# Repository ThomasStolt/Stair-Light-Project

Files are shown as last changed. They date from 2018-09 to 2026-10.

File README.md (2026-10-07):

# Stair Light Project

Automatic animated stair lighting with **SK6812 RGBW** LEDs. Two PIR sensors (SR-HC501) at the first and last step detect direction and trigger a random animation. Control via a phone-friendly **web UI** (motion automation on/off, playing animations, fixed colour, device status, settings and birthdays) and optional **night mode** (configurable hours: soft red light only).

- **MCU:** ESP8266 (e.g. NodeMCU)
- **LEDs:** SK6812 RGBW (WS2812-compatible), 27 LEDs per step, 16 steps (configurable)
- **Sensors:** PIR1 = “up”, PIR2 = “down”
- **Boot:** Three soft green-white pulses (2 s) signal “ready”. Motion automation comes back as it was last set (on for a new device).

<div align="center">
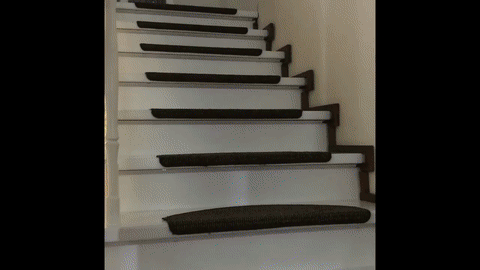
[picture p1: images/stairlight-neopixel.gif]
Stair Light test bed
  
</div>

---

## Requirements

- **Arduino CLI** (e.g. `brew install arduino-cli`)
- **ESP8266 core:**  
  `arduino-cli core update-index && arduino-cli core install esp8266:esp8266`
- **Libraries:**  
  `arduino-cli lib install "Adafruit NeoPixel"`  
  `arduino-cli lib install "EasyNTPClient"`

---

## Project structure

| Folder/File | Description |
|---|---|
| `rgbw_stair_light/` | Main sketch (stair light + OTA) |
| `rgbw_stair_light/parking.h` | Animations and helpers |
| `rgbw_stair_light/web_ui.h` | Web UI page (HTML/CSS/JS, served from flash) |
| `rgbw_stair_light/birthdays.h.example` | Template for birthdays (copy to `birthdays.h`) |
| `schematics/` | KiCad schematic, PCB |
| `images/` | Photos (incl. test bed) |

**Scripts (project root):**

| Script | Purpose |
|---|---|
| `upload-to-esp8266.sh` | Compile + upload **via USB** |
| `upload-to-esp8266-ota.sh` | Upload **via OTA** (WiFi) to one or more devices; compiles only when the sketch changed |
| `upload-ota-firewall-ok.sh` | OTA with **firewall temporarily disabled** (macOS) |
| `setup-firewall-ota.sh` | Add firewall rule for OTA (macOS, sudo) |

---

## Setup

### 1. WiFi and hostname

Credentials go in **`rgbw_stair_light/credentials.h`** (gitignored).

- Copy `credentials.h.example` to `credentials.h` and set:
  - `WIFI_SSID` – your Wi‑Fi name  
  - `WIFI_PASS` – Wi‑Fi password  
  - `OTA_HOSTNAME` – e.g. `stairlight-testbed` or `stairlight`

Without `credentials.h` the build fails.

> The hostname can also be changed at runtime in the web UI (**Settings** section); it is stored in flash and applied on the next reboot. `OTA_HOSTNAME` in `credentials.h` is only the default used on first boot.

### 2. Birthdays (optional)

On dates listed in **`rgbw_stair_light/birthdays.h`**, only the birthday animation runs.

- **`birthdays.h`** is in `.gitignore` and is not committed.
- Copy `birthdays.h.example` to `birthdays.h`, set `BIRTHDAY_COUNT` and the `BIRTHDAY(month, day)` list (e.g. `BIRTHDAY(3, 15)` = 15 March).
- Without `birthdays.h` the build fails – after cloning, copy the example (use 0 entries if you don’t need birthdays).

### 3. Firewall (macOS, only if OTA fails)

If OTA fails with the firewall on:

- **Option A – rule via CLI:**  
  `sudo ./setup-firewall-ota.sh`  
  (allows Arduino Python and Terminal/Cursor to accept incoming connections)

- **Option B – OTA with firewall briefly off:**  
  `./upload-ota-firewall-ok.sh stairlight-testbed.local`  
  (firewall is disabled only during the upload, then re-enabled)

---

## First upload: via USB

1. Connect the ESP8266 via USB.
2. Check port (optional):  
   `arduino-cli board list`
3. From the project folder run:

   ```bash
   ./upload-to-esp8266.sh
   ```

   Default port is `/dev/cu.usbserial-0001`. To use another port:

   ```bash
   ./upload-to-esp8266.sh /dev/cu.wchusbserial-12345
   ```

4. After a successful upload the ESP connects to Wi‑Fi and is ready for OTA.

---

## Upload via OTA (WiFi)

Prerequisite: the ESP is already running firmware with **ArduinoOTA** (e.g. after the first USB upload) and is on the same Wi‑Fi network. The OTA script uses **espota.py** (no board discovery required); pass the ESP’s IP or mDNS hostname.

- **By hostname (mDNS):**  
  ```bash
  ./upload-to-esp8266-ota.sh stairlight-testbed.local
  ```

- **By IP:**  
  ```bash
  ./upload-to-esp8266-ota.sh 192.168.2.185
  ```

- **Several devices in one go** (same build for all, password asked once):  
  ```bash
  ./upload-ota-firewall-ok.sh 192.168.1.50 192.168.1.51
  ```

The IP is shown in the serial monitor after “Connected, IP address:” or “Web server: http://…”.

**Web UI:** Open `http://<IP>` or `http://<hostname>.local` in a browser. The page is made for phones. Its fonts load from Google Fonts when the phone has internet; without internet it uses the system font.

- **Header** – Device name, WiFi network and the device's local time (NTP).
- **Notices** – Night mode with its hours (“Night mode active” during night hours), and “Not connected, retrying” when the device can't be reached.
- **Motion automation** – On/off switch. The setting is saved on the device and survives restarts and power cuts.
- **Play an animation** – Tiles with live previews: Rainbow, Star sparkle, Birthday, Night red, White ramp and Matrix. A tap plays the animation for 10 s (Matrix: 60 s, `MATRIX_WEB_MS`). The tile of the animation that is running, whether started from the page or by motion, shows a progress ring.
- **Fixed colour** – Sliders for the red, green, blue and white LEDs (0–100 %) with a colour preview, and **All** presets (Off, 25 %, 50 %, 75 %, 100 %). Shown on the stairs while motion automation is off.
- **Recent motion** – The last 5 motion triggers with direction, animation and time.
- **Device** – Memory, flash and WiFi signal at a glance (percent and absolute values), last restart and uptime, plus a table with IP, gateway, DNS, network and channel, access point, reconnects, CPU, restart reason, free memory, largest free block, fragmentation and space left for updates.
- **Settings** – Device name (applied after a restart), night mode on/off and its hours.
- **Birthdays** – Add, edit and remove up to 20 birthdays.
- **Restart device** – With a confirmation on the page.
- **Firmware version** – At the bottom of the page.

The browser caches the page for an hour, so reload it after a firmware update. The page talks to the device through a small JSON API: `GET /api/state` (automation, colour, night mode, running animation), `/api/time`, `/api/log`, `/api/memory`, `/api/sysinfo`, `/api/settings`, `/api/birthdays`, and `POST /api/auto`, `/api/color`, `/api/play` (`anim=2..7`), `/api/settings`, `/api/birthdays`, `/api/reboot`. The web server keeps answering while an animation runs; OTA uploads only work between animations.

**If the firewall (macOS) blocks OTA:**  
Use the wrapper script instead of `upload-to-esp8266-ota.sh`:

```bash
./upload-ota-firewall-ok.sh stairlight-testbed.local
```

The firewall is then disabled only during the upload and re-enabled afterwards.

**espota debug output:**  
```bash
./upload-to-esp8266-ota.sh stairlight-testbed.local --debug
```

---

## Serial monitor

Baud rate: **115200**.

- **Via task (Cursor/VS Code):**  
  `Cmd+Shift+P` → “Tasks: Run Task” → “Serial Monitor (115200 Baud)” → enter port.

- **Via terminal:**  
  ```bash
  arduino-cli monitor -p /dev/cu.usbserial-0001 -c baudrate=115200
  ```

Adjust the port if needed (`arduino-cli board list`). Exit with `Ctrl+C`. While the monitor is running the USB port is in use (no upload).

**Note:** With `USE_SERIAL.setDebugOutput(true)` in the sketch, the ESP8266 WiFi library also prints connection messages (`state:`, `reconnect`, `scandone`, etc.). For a quieter monitor you can set `setDebugOutput(false)` to see only PIR/NTP and your own messages.

---

## Night mode (1–6 h)

Between **1:00 and 6:00 local time** (NTP + auto CET/CEST):

- Only the **night animation** runs: soft breathing red, max 20% brightness, **never fully off** (minimum brightness is configurable).
- PIR triggers the night animation; manual web colours have no effect.
- After 6:00 the strip turns off and normal behaviour (automation/manual) applies again.
- The web UI shows a **“Night mode active”** notice during night hours.

The night animation can be tested anytime in the web UI: tap **Night red** under **Play an animation** (10 s).

---

## Birthdays

Birthdays (month, day, and an optional name) trigger the birthday animation on the day.
They are editable in the web UI under **Birthdays** — add or remove rows and click Save —
and are stored in flash (up to 20 entries), surviving reboots. `birthdays.h` is only the
first-boot default; after that the saved list is authoritative.

API:

```bash
curl http://<host>/api/birthdays
# [{"m":11,"d":19,"name":"Anna"}, ...]
```

`POST /api/birthdays` replaces the whole list (form-encoded: `count=N` then `m<i>`,
`d<i>`, `n<i>` for each entry). Months 1–12, days 1–31, names up to 19 characters
(letters, digits, space, `-` `_` `.`).

## External control API

Another process on the same network can drive the strip directly, bypassing motion
detection — e.g. a parking/garage helper signalling stop/go.

`POST /api/ext` with form field `state`:

| `state` | Effect |
|---|---|
| `red` | Solid red, held until the next command |
| `red_blink` | Red blinking every 500 ms |
| `green_fade` | Green dimming from full to off over ~30 s, then auto-clears |
| `yellow_blink` | Yellow (red + green) blinking every 500 ms |
| `clean` | All LEDs fade up to near-max (R+G+B+W = 250) for cleaning; fades out on stop; auto-off after 10 min |
| `clear` | LEDs off immediately, override released |

While a command is active, motion detection is suppressed. After `green_fade` finishes
(or `clear`), normal behaviour resumes — daytime automation, or night mode if within
the configured night hours. No authentication (trusted LAN only). An `/api/ext` command
also **interrupts a running motion animation** (it aborts within ~1–2 s rather than
waiting for the animation and its post-delay to finish).

The held states (`red`, `red_blink`, `yellow_blink`) stay active until the next command,
but have a **5-minute safety timeout**: if no new `/api/ext` command arrives within 5
minutes, the override releases automatically and normal operation resumes (so the stairs
can't get stuck if the controller crashes or loses WiFi). Each command resets the timer.
`green_fade` self-terminates after ~30 s.

```bash
curl -X POST -d state=red        http://<host>/api/ext
curl -X POST -d state=red_blink    http://<host>/api/ext
curl -X POST -d state=green_fade   http://<host>/api/ext
curl -X POST -d state=yellow_blink http://<host>/api/ext
curl -X POST -d state=clean        http://<host>/api/ext
curl -X POST -d state=clear        http://<host>/api/ext
```

### Siri / Apple Shortcuts ("Staubsaugen")

Siri can't call the ESP directly, but an Apple **Shortcut** can, and Siri runs Shortcuts by
name. Create two shortcuts in the Shortcuts app (iPhone/iPad/Mac):

1. **"Staubsaugen"** (cleaning light on):
   - Add action **Get Contents of URL**
   - URL: `http://stairlight.local/api/ext` (or the device IP, e.g. `http://<device-ip>/api/ext`)
   - Method: **POST**, Request Body: **Form**, add field `state` = `clean`
2. **"Staubsaugen aus"** (off):
   - Same action/URL, field `state` = `clear`

Then say **"Hey Siri, Staubsaugen!"** to turn all LEDs to full brightness (auto-off after
10 minutes) and **"Hey Siri, Staubsaugen aus!"** to turn it off. The device must be reachable
on the same network (mDNS name `stairlight.local`, or use a DHCP-reserved IP).

#### Siri / Kurzbefehle einrichten (Deutsch)

Siri kann den ESP nicht direkt ansprechen, aber Siri führt **Kurzbefehle** (Shortcuts)
per Namen aus. Lege dafür zwei Kurzbefehle in der **Kurzbefehle**-App (iPhone/iPad/Mac) an:

1. **Kurzbefehl „Staubsaugen"** (Licht an):
   - Aktion **„Inhalte von URL abrufen"** hinzufügen
   - URL: `http://stairlight.local/api/ext` (oder die Geräte-IP, z. B. `http://<device-ip>/api/ext`)
   - Auf **▸ Mehr anzeigen** tippen: **Methode** = `POST`, **Anfragetext** = `Formular`,
     Feld **`state`** = `clean`
2. **Kurzbefehl „Staubsaugen aus"** (Licht aus): gleich wie oben, aber Feld **`state`** = `clear`

Dann **„Hey Siri, Staubsaugen!"** schaltet alle LEDs auf volle Helligkeit (sanft hochdimmen,
automatische Abschaltung nach 10 Minuten) und **„Hey Siri, Staubsaugen aus!"** dimmt wieder
herunter. Hinweise: Das iPhone muss im selben WLAN sein; beim ersten Mal fragt iOS nach der
Erlaubnis für das lokale Netzwerk → **Erlauben**. Falls `stairlight.local` nicht auflöst, die
IP verwenden (am besten im Router eine feste IP / DHCP-Reservierung vergeben).

Night mode (enable + start/end hours) and the hostname are configurable in the web UI
**Settings** section and persist across reboots.

---

## Sketch configuration

In **`rgbw_stair_light/rgbw_stair_light.ino`** (and `parking.h`):

| Constant | Meaning | Default |
|---|---|---|
| `STEPS` | Number of steps | 16 |
| `WIDTH` | LEDs per step | 27 |
| `ANIM_DURATION` | Duration of a PIR-triggered animation (ms) | 20000 |
| `POST_ANIM_DELAY_MS` | Delay after animation before next trigger (ms) | 10000 |
| `BRIGHTNESS` | LED brightness 0–255 | 255 |
| `DEBUG` | 1 = PIR/trigger on serial monitor | 1 |
| `TIMEZONE_OFFSET_SEC` | Seconds UTC→local (e.g. 3600 for CET) | 3600 |
| `FW_VERSION` | Firmware version string shown in web UI | "2.1.0" |
| `NIGHT_HOUR_START` / `NIGHT_HOUR_END` | Night mode from hour … to (excl.) | 1, 6 |
| `NIGHT_BRIGHTNESS_MAX` / `NIGHT_BRIGHTNESS_MIN` | Red in night mode max/min (0–255) | 50, 10 |

Pins (see comments in sketch): NeoPixel = GPIO 14 (D5), PIR1 = GPIO 16 (D0), PIR2 = GPIO 4 (D2). Do not use GPIO 15 and 2 (boot behaviour).

---

## Animations

Direction (up/down) is detected via PIR1/PIR2. With stair automation on, a random one of these animations runs (no back-to-back repeat):

- **Rainbow** (`rainbowSteps`) – steps fade in as a wave, colours flow in walking direction  
- **White ramp** (`FadeToFullBrightness`) – all steps to white  
- **Star sparkle** (`starSparkle`) – dark blue backdrop with white stars that light up and fade out  
- **Matrix** (`matrixRain`) – green digital rain falling down the stairs

On **birthdays** (from the web UI / `birthdays.h`) the **birthday animation** runs instead: random colours on about three quarters of the LEDs, each glowing and fading. At night (night mode hours) motion turns on a soft red light (**Night red**, `nightAnimation`).

In the web UI you can play each of these, plus Birthday and Night red, for 10 seconds (Matrix: 60 seconds).

More functions and possible new animations are in **`parking.h`**.

---

## License / contact

Originally from October 2016; sketch and structure have been extended (OTA, credentials, web API, night mode, birthdays, firewall workaround, date/time, reboot, motion log, memory status table, All presets, automation on by default, OTA via espota.py, night mode indicator, firmware version display).

For questions or ideas for new animations, contact the repository owner.

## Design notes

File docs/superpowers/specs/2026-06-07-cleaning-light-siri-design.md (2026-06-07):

# Cleaning Light ("Staubsaugen") + Siri — Design

**Date:** 2026-06-07
**Component:** `rgbw_stair_light/rgbw_stair_light.ino` (+ README, CHANGELOG); Apple Shortcuts (user side)
**Status:** Approved

## Goal

A voice-triggered "cleaning light": "Hey Siri, Staubsaugen!" turns every LED to full
brightness for vacuuming, and it stays on for **10 minutes** or until "Hey Siri,
Staubsaugen aus!" turns it off. Brightness = **all channels at 255** (R+G+B+W max),
per user choice (brightest; note the high sustained current draw across 432 LEDs).

## Approach

Reuse the existing external-control state machine (`/api/ext`) — it already provides a
held override that suppresses motion automation and night mode while active and restores
normal operation when released. Add a new held state `clean`:

- `POST /api/ext state=clean` → all LEDs `setAll(255,255,255,255)`, held.
- Auto-off after **10 minutes** (its own timeout, distinct from the 5-min timeout used by
  the red/yellow held states). Each `clean` command resets the timer.
- `POST /api/ext state=clear` → off, override released (this is "Staubsaugen aus").

Siri integration is done with two Apple Shortcuts (no firmware involvement): a Shortcut
named **"Staubsaugen"** that POSTs `state=clean`, and **"Staubsaugen aus"** that POSTs
`state=clear`. Saying "Hey Siri, <shortcut name>" runs the matching Shortcut.

## Firmware changes

1. `enum ExtMode` gains `EXT_CLEAN`; command code `6`.
2. `#define EXT_CLEAN_TIMEOUT_MS 600000uL` (10 min).
3. `handleApiExt()` accepts `state=clean` → cmd 6 (and the help/error strings list it).
4. `applyExtCommand()` case 6: `EXT_CLEAN`, `g_extActive=true`, `setAll(255,255,255,255)`,
   `strip.show()`. (`g_extLastCmdMs` is already set for every command at the top.)
5. `serviceExtControl()` timeout guard includes `EXT_CLEAN`, using `EXT_CLEAN_TIMEOUT_MS`
   instead of the 5-min `EXT_HOLD_TIMEOUT_MS` for that mode; on timeout it clears
   (LEDs off, `EXT_NONE`, `g_extActive=false`) exactly like the other held states. `clean`
   is a solid state, so the blink/fade branches don't touch it.

No new routes; reuses `POST /api/ext`.

## Siri / Apple Shortcuts (documented for the user)

Two Shortcuts (Shortcuts app → +):
- **"Staubsaugen"**: action *Get Contents of URL* → `http://stairlight.local/api/ext`,
  Method `POST`, Request Body `Form`, field `state` = `clean`.
- **"Staubsaugen aus"**: same URL, `state` = `clear`.

"Hey Siri, Staubsaugen" / "Hey Siri, Staubsaugen aus" then trigger them. (Phone must be on
the same WiFi / reachable; `stairlight.local` resolves via mDNS, or use the IP.)

## Error handling / edge cases

- Re-sending `clean` resets the 10-min timer (keepalive).
- Works during night hours (override suppresses night mode); normal behaviour resumes on
  timeout/clear.
- `millis()` subtraction is rollover-safe.
- Power: all-channels-255 for 432 LEDs is a heavy sustained load — documented as a caution.

## Testing

Compile clean; on-device: `state=clean` → strip full white, `state=clear` → off + normal
resumes. (Full 10-min wait impractical by hand; timeout uses the same proven path as the
existing held-state timeout.)

## Out of scope

- A dedicated `/api/clean` route (reusing `/api/ext` is simpler).
- Configurable brightness/duration via the API or UI.

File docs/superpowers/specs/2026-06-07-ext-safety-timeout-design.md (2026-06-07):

# External-Control Safety Timeout — Design

**Date:** 2026-06-07
**Component:** `rgbw_stair_light/rgbw_stair_light.ino` (+ README, CHANGELOG)
**Status:** Approved

## Goal

Prevent the stairs from getting stuck in an external-control state. The held states
(`red`, `red_blink`, `yellow_blink`) currently stay active indefinitely until the
controller sends another command. If the controller crashes or loses WiFi, the strip
would remain overridden forever. Add a **5-minute safety timeout**: if no new `/api/ext`
command arrives within 5 minutes, the override releases automatically and normal operation
(motion automation / night mode, exactly as before) resumes.

## Decisions

- **Timeout:** 5 minutes (300 s).
- **Applies to:** the held states only — `red`, `red_blink`, `yellow_blink`. `green_fade`
  already self-terminates after ~30 s, so the timeout is irrelevant to it (and not applied).
- **Reset on activity:** every received `/api/ext` command resets the 5-minute timer
  (timer is measured from the last command, not from the first).
- **On timeout:** identical to `clear` — LEDs off, `g_extActive=false`, `g_extMode=EXT_NONE`;
  `loop()` then resumes whatever normal behaviour was in effect before (automation on/off is
  never modified by external control, so "normal operations from before" is preserved).

## Implementation

In the existing external-control state machine:

1. `#define EXT_HOLD_TIMEOUT_MS 300000uL` (5 min).
2. New global `unsigned long g_extLastCmdMs = 0;` — timestamp of the most recent command.
3. `applyExtCommand()` sets `g_extLastCmdMs = millis()` for every command (resets the timer).
4. `serviceExtControl()` (already called every loop iteration while `g_extActive`) gets a
   guard at the top: if the current mode is `EXT_RED` / `EXT_RED_BLINK` / `EXT_YELLOW_BLINK`
   and `millis() - g_extLastCmdMs >= EXT_HOLD_TIMEOUT_MS`, turn LEDs off, set
   `g_extMode=EXT_NONE`, `g_extActive=false`, and return. `green_fade` is excluded.

`millis()` subtraction is rollover-safe (unsigned). No change to the API surface, routes,
or any other behaviour.

## Error handling / edge cases

- A new command mid-hold resets the timer (controller "keepalive" keeps a state active).
- `clear` and `green_fade` are unaffected (clear releases immediately; green_fade ends in 30 s).
- Rollover at ~49 days is handled by the unsigned `now - g_extLastCmdMs` idiom.

## Testing

No unit harness (firmware). Verify: compile clean; on-device, send `red`/`yellow_blink`,
confirm it holds, then send `clear` to stop (full 5-min wait is impractical to verify by
hand but the logic mirrors the proven `green_fade` auto-clear). Confirm normal operation
resumes after `clear`/timeout.

## Out of scope

- Per-command custom durations (`secs=`).
- Applying the timeout to `green_fade` (already self-terminating).

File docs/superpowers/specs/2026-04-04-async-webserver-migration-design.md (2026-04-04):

# AsyncWebServer Migration & Web UI Redesign

**Date:** 2026-04-04
**Status:** Approved

## Goal

Migrate from `ESP8266WebServer` (synchronous) to `ESPAsyncWebServer` (async) for improved web UI responsiveness, and redesign the web UI with sliders, individual animation buttons, collapsible diagnostics, and tiered polling.

## Approach: Incremental (Two Phases)

Phase 1 swaps the server library while keeping the existing UI identical. Phase 2 redesigns the UI. This separation ensures that if something breaks, the cause is obvious — library vs. UI change.

## Constraints

- ESP8266 (NodeMCU), ~37 kB free heap available
- HTML stays embedded in PROGMEM (no LittleFS) — single OTA binary deploy
- OTA must remain functional throughout
- All existing API response formats preserved

---

## Phase 1: AsyncWebServer Library Swap

### Dependencies

Replace:
- `#include <ESP8266WebServer.h>`

With:
- `#include <ESPAsyncTCP.h>`
- `#include <ESPAsyncWebServer.h>`

### Server Declaration

```cpp
// Before
ESP8266WebServer server(80);

// After
AsyncWebServer server(80);
```

### Handler Conversion

All handlers change signature from using the global `server` object to receiving an `AsyncWebServerRequest*` parameter.

**Pattern:**
```cpp
// Before
void handleApiState() {
  server.sendHeader(F("Cache-Control"), F("no-store"));
  server.send(200, F("application/json"), json);
}

// After
void handleApiState(AsyncWebServerRequest *request) {
  AsyncWebServerResponse *response = request->beginResponse(200, F("application/json"), json);
  response->addHeader(F("Cache-Control"), F("no-store"));
  request->send(response);
}
```

**Parameter access changes:**
- `server.hasArg(F("on"))` → `request->hasParam(F("on"), true)` (second arg `true` = POST body param)
- `server.arg(F("on"))` → `request->getParam(F("on"), true)->value()`
- `server.method() != HTTP_POST` checks are no longer needed — routes are registered with `HTTP_POST` method directly, so only matching methods reach the handler

### Route Registration

```cpp
// Before
server.on(F("/"), handleIndex);
server.on(F("/api/state"), HTTP_GET, handleApiState);
server.on(F("/api/auto"), HTTP_POST, handleApiAuto);

// After
server.on("/", HTTP_GET, handleIndex);
server.on("/api/state", HTTP_GET, handleApiState);
server.on("/api/auto", HTTP_POST, handleApiAuto);
```

Note: `AsyncWebServer::on()` does not accept `F()` macro for the path string. Use plain string literals.

### Remove handleNetwork()

Delete the `handleNetwork()` function (lines 164, 168–171 in .ino) and remove all calls to it:
- ~5 calls in `rgbw_stair_light.ino` (main loop, wait loops)
- ~17 calls in `parking.h` (inside animation loops)

With AsyncWebServer, requests are handled via interrupts — no manual pumping is needed.

`ArduinoOTA.handle()` still needs to be called in `loop()` — move it from `handleNetwork()` to the main loop directly.

### Remove server.handleClient()

No longer needed — delete from loop and from `handleApiReboot`.

### Refactor handleApiPlay (Flag-Based)

The current handler runs animations synchronously inside the request handler. AsyncWebServer handlers must return quickly (they execute in the TCP context).

**Solution:** Handler sets a flag, `loop()` picks it up:

```cpp
volatile int g_pendingPlayAnim = 0;  // 0 = none, 1–6 = animation to play

void handleApiPlay(AsyncWebServerRequest *request) {
  if (!request->hasParam("anim", true)) {
    request->send(400, F("text/plain"), F("anim=1..6"));
    return;
  }
  int anim = request->getParam("anim", true)->value().toInt();
  if (anim < 1 || anim > 6) {
    request->send(400, F("text/plain"), F("anim 1..6"));
    return;
  }
  g_pendingPlayAnim = anim;
  request->send(204);
}

// In loop(), after handleNetwork removal:
if (g_pendingPlayAnim > 0) {
  int anim = g_pendingPlayAnim;
  g_pendingPlayAnim = 0;
  // run animation (same logic as current handleApiPlay body)
}
```

### Refactor handleApiReboot (Flag-Based)

Like `handleApiPlay`, the reboot handler must not block. Use a flag that `loop()` checks:

```cpp
volatile bool g_pendingReboot = false;

void handleApiReboot(AsyncWebServerRequest *request) {
  g_pendingReboot = true;
  request->send(204);
}

// In loop():
if (g_pendingReboot) {
  delay(300);  // give async stack time to flush the 204 response
  ESP.restart();
}
```

### Thread Safety Note

AsyncWebServer on ESP8266 uses async TCP callbacks (from the lwIP stack), not a separate thread. The ESP8266 is single-core with cooperative multitasking. Shared variables (`g_pendingPlayAnim`, `g_pendingReboot`, `manual_r/g/b/w`, `automationOn`) are accessed from both async callbacks and `loop()`. On ESP8266 this is safe for simple flag/value reads and writes (single-core, no preemption between instructions), but avoid multi-step read-modify-write sequences in handlers.

### Phase 1 Verification

After Phase 1, all existing endpoints must work identically:
- `GET /` serves the same HTML
- `GET /api/state`, `/api/time`, `/api/log`, `/api/memory`, `/api/sysinfo` return same JSON formats
- `POST /api/auto`, `/api/color`, `/api/alloff`, `/api/play`, `/api/reboot` behave the same
- OTA upload works
- PIR-triggered animations work
- Night mode works
- Web UI functions identically (it's the same HTML)

---

## Phase 2: Web UI Redesign

### Layout: Collapsible Diagnostics

Top-to-bottom, single scrollable page:

1. **Header**: "Stair Light" title, date, time, uptime, last reboot
2. **Automation**: On/Off toggle buttons + night mode badge (conditional)
3. **RGBW Sliders**: One `<input type="range">` per channel (0–100%), colored LED indicator dot, percentage label
4. **All-Channel Presets**: Row of buttons: 0% / 25% / 50% / 75% / 100%
5. **Animation Buttons**: 6 individual color-coded buttons (one per animation)
6. **Reboot**: Single button
7. **Collapsible Diagnostics** (using `<details>/<summary>`):
   - Last 5 motions (table)
   - Memory status (table: heap/flash/RTC)
   - CPU / Runtime (table: freq, reset reason)
   - WiFi (table: SSID, RSSI, IP, gateway, DNS, channel, reconnects)
8. **Footer**: Firmware version

### RGBW Sliders

Each channel row:
```
[colored dot] =====[slider]===== [percentage%]
```

- HTML: `<input type="range" min="0" max="100" value="0">`
- Slider track styled to match channel color (red/green/blue/white)
- On `input` event, debounced to ~100ms, sends POST to `/api/color`

### API Addition: Direct Value Set

Add `v=<0-100>` parameter to `/api/color` for direct value setting (used by sliders):

```
POST /api/color
Body: c=r&v=70
```

Sets channel `r` to exactly 70%. Existing `a=minus`/`a=plus`/`a=toggle` parameters continue to work (backward compatible). The preset buttons use: `POST /api/color` with `all=<value>` (unchanged).

### Animation Buttons

Six buttons, each sending `POST /api/play` with `anim=1..6`:

| Button | Animation | Color Theme |
|---|---|---|
| Random fade | `anim=1` | Green |
| Rainbow | `anim=2` | Blue/cyan |
| White ramp | `anim=3` | White/gray |
| Star sparkle | `anim=4` | Dark blue/purple |
| Birthday | `anim=5` | Pink/magenta |
| Night red | `anim=6` | Red |

Buttons show a pressed/active state on tap for visual feedback.

### Tiered Polling

**Fast tier — every 2 seconds:**
- `GET /api/state` — automation status, RGBW percentages, night mode flag
- `GET /api/time` — date, time, uptime, last reboot

**Slow tier — every 15 seconds, only when expanded:**
- `GET /api/log` — only polled when "Last 5 motions" `<details>` is open
- `GET /api/memory` — only polled when "Memory status" `<details>` is open
- `GET /api/sysinfo` — only polled when "CPU/Runtime" or "WiFi" `<details>` is open

When all diagnostic sections are collapsed, only 2 requests every 2 seconds (down from 5 every 1 second = 60% reduction in baseline traffic).

### Slider Debouncing

As the user drags a slider, `input` events fire rapidly. To avoid flooding the ESP:
- Track the latest value per channel
- Use a 100ms debounce timer — only send the POST when 100ms have passed since the last `input` event
- This means at most ~10 requests/second during active dragging, and the ESP always gets the final value

### Styling

- Dark theme preserved (`background: #1a1a1a`, light text)
- Same overall aesthetic as current UI (dark card backgrounds, colored accents)
- Mobile-first, max-width ~420px, responsive
- `<details>` elements styled to match the dark theme

---

## Files Modified

- `rgbw_stair_light/rgbw_stair_light.ino` — server library swap, handler conversion, HTML rewrite, new `v=` param in handleApiColor
- `rgbw_stair_light/parking.h` — remove all `handleNetwork()` calls

## Files Not Modified

- `rgbw_stair_light/credentials.h`
- `rgbw_stair_light/birthdays.h`
- Upload scripts (`upload-to-esp8266.sh`, `upload-to-esp8266-ota.sh`)
- Animation logic in `parking.h` (only `handleNetwork()` removal)

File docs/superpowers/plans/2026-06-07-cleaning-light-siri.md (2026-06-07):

# Cleaning Light ("Staubsaugen") + Siri — Implementation Plan

> Direct implementation. Adds a `clean` held state to the existing `/api/ext` machine with a 10-minute auto-off. Compile gate: `arduino-cli compile --fqbn esp8266:esp8266:nodemcu rgbw_stair_light`.

**File:** `rgbw_stair_light/rgbw_stair_light.ino` (+ `CHANGELOG.md`, `README.md`). Siri side = Apple Shortcuts (documented, no code).

## Steps

1. **Enum + command code.** `enum ExtMode { ... , EXT_YELLOW_BLINK };` → append `, EXT_CLEAN`. Update the `g_pendingExtCmd` comment to add `,6=clean`.
2. **Timeout define.** After `#define EXT_HOLD_TIMEOUT_MS 300000uL ...` add `#define EXT_CLEAN_TIMEOUT_MS 600000uL // clean (full brightness) auto-clears after 10 min`.
3. **Handler.** In `handleApiExt()`: add `else if (s == F("clean")) cmd = 6;`; add `clean` to the comment and both 400 help strings (`state=red|red_blink|green_fade|yellow_blink|clean|clear`).
4. **applyExtCommand().** Add before `case 4`:
   ```cpp
   case 6: // clean – all channels full brightness, held (10 min timeout)
     g_extMode = EXT_CLEAN; g_extActive = true;
     setAll(255, 255, 255, 255); strip.show();
     break;
   ```
5. **serviceExtControl() timeout guard.** Replace the held-state timeout block with one that includes `EXT_CLEAN` and uses a per-mode timeout:
   ```cpp
   if (g_extMode == EXT_RED || g_extMode == EXT_RED_BLINK ||
       g_extMode == EXT_YELLOW_BLINK || g_extMode == EXT_CLEAN) {
     unsigned long holdTimeout = (g_extMode == EXT_CLEAN) ? EXT_CLEAN_TIMEOUT_MS : EXT_HOLD_TIMEOUT_MS;
     if (now - g_extLastCmdMs >= holdTimeout) {
       setAll(0, 0, 0, 0); strip.show();
       g_extMode = EXT_NONE;
       g_extActive = false;
       return;
     }
   }
   ```
6. **Version:** `FW_VERSION` `2.4.0` → `2.5.0`.
7. **Docs:** CHANGELOG `2.5.0` entry; README — add `clean` to the `/api/ext` table + a "Siri / Apple Shortcuts" subsection with the two Shortcut definitions.
8. **Compile, commit, OTA-flash to device, push to GitHub.**

## Self-review

- `clean` = all-channels-255, held, 10-min auto-off; `clear` = off ("Staubsaugen aus") ✓.
- Per-mode timeout (10 min for clean, 5 min for others) ✓; timer reset on every command ✓.
- Solid state — not touched by blink/fade branches ✓. Rollover-safe ✓. No new routes ✓.
- Siri documented as two Shortcuts POSTing `state=clean` / `state=clear` ✓.

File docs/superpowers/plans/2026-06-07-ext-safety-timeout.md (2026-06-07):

# External-Control Safety Timeout — Implementation Plan

> Direct implementation (single small, mechanical change to the existing ext state machine). Compile gate: `arduino-cli compile --fqbn esp8266:esp8266:nodemcu rgbw_stair_light`.

**Goal:** Held external-control states (`red`, `red_blink`, `yellow_blink`) auto-release after 5 minutes with no new `/api/ext` command, returning to normal operation.

**File:** `rgbw_stair_light/rgbw_stair_light.ino` (+ `CHANGELOG.md`, `README.md`).

## Steps

1. **Define + global.** After `bool g_extBlinkOn = false;` add:
   - `#define EXT_HOLD_TIMEOUT_MS 300000uL  // 5 min`
   - `unsigned long g_extLastCmdMs = 0;     // last /api/ext command time (for hold timeout)`
2. **Reset timer on every command.** In `applyExtCommand()`, after `unsigned long now = millis();`, add `g_extLastCmdMs = now;`.
3. **Timeout guard.** At the top of `serviceExtControl()` (after `unsigned long now = millis();`), before the blink/fade branches:
   ```cpp
   // Safety timeout: a held state auto-clears after 5 min with no new command,
   // so the stairs can't get stuck if the controller dies. green_fade is excluded
   // (it self-terminates in ~30 s).
   if (g_extMode == EXT_RED || g_extMode == EXT_RED_BLINK || g_extMode == EXT_YELLOW_BLINK) {
     if (now - g_extLastCmdMs >= EXT_HOLD_TIMEOUT_MS) {
       setAll(0, 0, 0, 0); strip.show();
       g_extMode = EXT_NONE;
       g_extActive = false;     // normal behaviour resumes next iteration
       return;
     }
   }
   ```
4. **Version:** bump `FW_VERSION` `2.3.0` → `2.4.0`.
5. **Docs:** CHANGELOG `2.4.0` entry; README external-control section notes the 5-min auto-release for held states.
6. **Compile, merge to master, OTA-flash to the device, push to GitHub.**

## Self-review

- Held states covered (red/red_blink/yellow_blink); green_fade excluded ✓.
- Timer reset on every command (measured from last command) ✓.
- Timeout path = clear semantics (LEDs off, override released, normal resumes) ✓.
- Rollover-safe unsigned subtraction ✓. No API/route changes ✓.

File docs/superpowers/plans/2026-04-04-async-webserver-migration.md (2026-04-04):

# AsyncWebServer Migration & Web UI Redesign — Implementation Plan

> **For agentic workers:** REQUIRED SUB-SKILL: Use superpowers:subagent-driven-development (recommended) or superpowers:executing-plans to implement this plan task-by-task. Steps use checkbox (`- [ ]`) syntax for tracking.

**Goal:** Migrate from ESP8266WebServer to ESPAsyncWebServer for non-blocking request handling, then redesign the web UI with sliders, animation buttons, collapsible diagnostics, and tiered polling.

**Architecture:** Two-phase incremental approach. Phase 1 (Tasks 1–3) swaps the server library while keeping the existing UI identical, so any breakage is clearly a library issue. Phase 2 (Tasks 4–6) redesigns the UI HTML/JS/CSS. All HTML stays embedded in PROGMEM.

**Tech Stack:** ESP8266 Arduino, ESPAsyncTCP, ESPAsyncWebServer, Adafruit NeoPixel, ArduinoOTA, EasyNTPClient

---

## File Structure

| File | Action | Responsibility |
|---|---|---|
| `rgbw_stair_light/rgbw_stair_light.ino` | Modify | Server setup, handlers, HTML, loop logic |
| `rgbw_stair_light/parking.h` | Modify | Remove all `handleNetwork()` calls from animations |

No new files are created.

---

## Phase 1: AsyncWebServer Library Swap

### Task 1: Replace includes, server declaration, and remove handleNetwork()

**Files:**
- Modify: `rgbw_stair_light/rgbw_stair_light.ino:27-41` (includes)
- Modify: `rgbw_stair_light/rgbw_stair_light.ino:92` (server declaration)
- Modify: `rgbw_stair_light/rgbw_stair_light.ino:98-99` (add pending anim/reboot globals)
- Modify: `rgbw_stair_light/rgbw_stair_light.ino:163-171` (handleNetwork declaration and definition)
- Modify: `rgbw_stair_light/parking.h:1` (remove ArduinoOTA include)
- Modify: `rgbw_stair_light/parking.h` (remove all handleNetwork() calls — 17 occurrences)

- [ ] **Step 1: Replace the include and server declaration in the .ino**

In `rgbw_stair_light/rgbw_stair_light.ino`, replace:
```cpp
#include <ESP8266WebServer.h>
```
with:
```cpp
#include <ESPAsyncTCP.h>
#include <ESPAsyncWebServer.h>
```

Replace:
```cpp
ESP8266WebServer server(80);
```
with:
```cpp
AsyncWebServer server(80);
```

- [ ] **Step 2: Add pending animation and reboot flag globals**

In `rgbw_stair_light/rgbw_stair_light.ino`, after line 99 (`uint32_t g_animDurationOverrideMs = 0;`), add:
```cpp
// Flags set by async web handlers, consumed by loop()
volatile int g_pendingPlayAnim = 0;   // 0 = none, 1-6 = animation to play
volatile bool g_pendingReboot = false;
```

- [ ] **Step 3: Remove handleNetwork() declaration and definition**

In `rgbw_stair_light/rgbw_stair_light.ino`, delete lines 163-164:
```cpp
// Called in animations and wait loops so OTA and web server stay responsive during animation
void handleNetwork(void);
```

Delete lines 168-171:
```cpp
void handleNetwork(void) {
  ArduinoOTA.handle();
  server.handleClient();
}
```

- [ ] **Step 4: Remove handleNetwork() calls from parking.h**

In `rgbw_stair_light/parking.h`, delete line 1:
```cpp
#include <ArduinoOTA.h>
```
(ArduinoOTA is already included in the .ino, and parking.h no longer calls handleNetwork which called ArduinoOTA.handle().)

Remove every `handleNetwork();` call in parking.h. These are on lines: 120, 157, 183, 197, 228, 242, 281, 295, 358, 370, 385, 429, 474, 480, 499. Delete each line entirely (they are standalone statements, not part of larger expressions).

- [ ] **Step 5: Remove handleNetwork() calls from the .ino loop**

In `rgbw_stair_light/rgbw_stair_light.ino`, replace every `handleNetwork();` in the loop and wait loops with `ArduinoOTA.handle();`. These are on lines: 732, 778, 790, 818.

The main loop still needs `ArduinoOTA.handle()` since OTA uses a different mechanism than the web server. The web server no longer needs pumping (async handles it).

- [ ] **Step 6: Compile check**

Run:
```bash
arduino-cli compile --fqbn esp8266:esp8266:nodemcuv2 rgbw_stair_light/
```

Expected: compilation errors for handler functions (they still use `server.send()` etc.) — that is fine, we fix those in Task 2. But the handleNetwork removal and includes should be clean.

If ESPAsyncTCP or ESPAsyncWebServer libraries are not installed:
```bash
arduino-cli lib install "ESPAsyncTCP"
arduino-cli lib install "ESP Async WebServer"
```

- [ ] **Step 7: Commit**

```bash
git add rgbw_stair_light/rgbw_stair_light.ino rgbw_stair_light/parking.h
git commit -m "Phase 1a: Replace ESP8266WebServer with ESPAsyncWebServer, remove handleNetwork()"
```

---

### Task 2: Convert all request handlers to async API

**Files:**
- Modify: `rgbw_stair_light/rgbw_stair_light.ino:207-295` (handleIndex)
- Modify: `rgbw_stair_light/rgbw_stair_light.ino:297-308` (handleApiState)
- Modify: `rgbw_stair_light/rgbw_stair_light.ino:310-318` (handleApiAuto)
- Modify: `rgbw_stair_light/rgbw_stair_light.ino:320-356` (handleApiColor)
- Modify: `rgbw_stair_light/rgbw_stair_light.ino:358-364` (handleApiAlloff)
- Modify: `rgbw_stair_light/rgbw_stair_light.ino:367-391` (handleApiPlay)
- Modify: `rgbw_stair_light/rgbw_stair_light.ino:393-432` (handleApiTime)
- Modify: `rgbw_stair_light/rgbw_stair_light.ino:435-442` (handleApiReboot)
- Modify: `rgbw_stair_light/rgbw_stair_light.ino:444-470` (handleApiLog)
- Modify: `rgbw_stair_light/rgbw_stair_light.ino:476-521` (handleApiMemory)
- Modify: `rgbw_stair_light/rgbw_stair_light.ino:539-558` (handleApiSysinfo)

- [ ] **Step 1: Convert handleIndex**

Replace the function with:
```cpp
void handleIndex(AsyncWebServerRequest *request) {
  AsyncWebServerResponse *response = request->beginResponse_P(200, "text/html", PSTR(
    // ... existing HTML string unchanged ...
  ));
  response->addHeader(F("Cache-Control"), F("public, max-age=3600"));
  request->send(response);
}
```

Note: `beginResponse_P` reads from PROGMEM. The HTML content string stays exactly the same as the current version. Keep all the existing HTML between `PSTR(` and `)` identical.

- [ ] **Step 2: Convert handleApiState**

Replace:
```cpp
void handleApiState() {
  String json = "{\"auto\":";
  json += automationOn ? "1" : "0";
  json += ",\"r\":"; json += manual_r;
  json += ",\"g\":"; json += manual_g;
  json += ",\"b\":"; json += manual_b;
  json += ",\"w\":"; json += manual_w;
  json += ",\"night\":"; json += isNightMode(g_lastNtpTime) ? "1" : "0";
  json += "}";
  server.sendHeader(F("Cache-Control"), F("no-store"));
  server.send(200, F("application/json"), json);
}
```
with:
```cpp
void handleApiState(AsyncWebServerRequest *request) {
  String json = "{\"auto\":";
  json += automationOn ? "1" : "0";
  json += ",\"r\":"; json += manual_r;
  json += ",\"g\":"; json += manual_g;
  json += ",\"b\":"; json += manual_b;
  json += ",\"w\":"; json += manual_w;
  json += ",\"night\":"; json += isNightMode(g_lastNtpTime) ? "1" : "0";
  json += "}";
  AsyncWebServerResponse *response = request->beginResponse(200, F("application/json"), json);
  response->addHeader(F("Cache-Control"), F("no-store"));
  request->send(response);
}
```

- [ ] **Step 3: Convert handleApiAuto**

Replace:
```cpp
void handleApiAuto() {
  if (server.method() != HTTP_POST) { server.send(405, F("text/plain"), F("Method Not Allowed")); return; }
  if (server.hasArg(F("on"))) {
    automationOn = (server.arg(F("on")).toInt() != 0);
    if (!automationOn) applyManualColor();
    else { setAll(0, 0, 0, 0); strip.show(); }
  }
  server.send(204);
}
```
with:
```cpp
void handleApiAuto(AsyncWebServerRequest *request) {
  if (request->hasParam(F("on"), true)) {
    automationOn = (request->getParam(F("on"), true)->value().toInt() != 0);
    if (!automationOn) applyManualColor();
    else { setAll(0, 0, 0, 0); strip.show(); }
  }
  request->send(204);
}
```

Note: The `HTTP_POST` method check is removed because the route is registered with `HTTP_POST` — only POST requests reach this handler. The second parameter `true` in `hasParam`/`getParam` means "search POST body parameters".

- [ ] **Step 4: Convert handleApiColor (with new v= parameter)**

Replace the entire `handleApiColor` function with:
```cpp
void handleApiColor(AsyncWebServerRequest *request) {
  if (request->hasParam(F("all"), true)) {
    int pct;
    if (request->hasParam(F("a"), true)) {
      String ax = request->getParam(F("a"), true)->value();
      int cur = (int)manual_r;
      if (ax == F("minus10")) pct = cur - 10;
      else if (ax == F("minus1")) pct = cur - 1;
      else if (ax == F("plus1")) pct = cur + 1;
      else if (ax == F("plus10")) pct = cur + 10;
      else { request->send(400, F("text/plain"), F("a=minus10|minus1|plus1|plus10")); return; }
      if (pct < 0) pct = 0;
      if (pct > 100) pct = 100;
    } else {
      pct = request->getParam(F("all"), true)->value().toInt();
      if (pct < 0) pct = 0;
      if (pct > 100) pct = 100;
    }
    manual_r = manual_g = manual_b = manual_w = (uint8_t)pct;
    if (!automationOn) applyManualColor();
    request->send(204);
    return;
  }
  // Direct value set: c=<channel>&v=<0-100> (used by sliders in Phase 2)
  if (request->hasParam(F("c"), true) && request->hasParam(F("v"), true)) {
    String c = request->getParam(F("c"), true)->value();
    int val = request->getParam(F("v"), true)->value().toInt();
    if (val < 0) val = 0;
    if (val > 100) val = 100;
    uint8_t* target = nullptr;
    if (c == F("r")) target = &manual_r;
    else if (c == F("g")) target = &manual_g;
    else if (c == F("b")) target = &manual_b;
    else if (c == F("w")) target = &manual_w;
    if (!target) { request->send(400, F("text/plain"), F("c=r|g|b|w")); return; }
    *target = (uint8_t)val;
    if (!automationOn) applyManualColor();
    request->send(204);
    return;
  }
  // Step adjust: c=<channel>&a=minus|plus|toggle
  if (!request->hasParam(F("c"), true) || !request->hasParam(F("a"), true)) {
    request->send(400, F("text/plain"), F("c and a (or v) required"));
    return;
  }
  String c = request->getParam(F("c"), true)->value();
  String a = request->getParam(F("a"), true)->value();
  uint8_t* v = nullptr;
  if (c == F("r")) v = &manual_r; else if (c == F("g")) v = &manual_g; else if (c == F("b")) v = &manual_b; else if (c == F("w")) v = &manual_w;
  if (!v) { request->send(400, F("text/plain"), F("c=r|g|b|w")); return; }
  if (a == F("minus")) { *v = (*v <= 10) ? 0 : (*v - 10); }
  else if (a == F("plus"))  { *v = (*v >= 90) ? 100 : (*v + 10); }
  else if (a == F("toggle")) { *v = (*v > 0) ? 0 : 50; }
  if (!automationOn) applyManualColor();
  request->send(204);
}
```

Note: This already includes the `v=<value>` direct-set parameter needed for Phase 2 sliders. Adding it now is harmless and saves a second touch of this handler later.

- [ ] **Step 5: Convert handleApiAlloff**

Replace:
```cpp
void handleApiAlloff() {
  if (server.method() != HTTP_POST) { server.send(405, F("text/plain"), F("Method Not Allowed")); return; }
  manual_r = manual_g = manual_b = manual_w = 0;
  setAll(0, 0, 0, 0);
  strip.show();
  server.send(204);
}
```
with:
```cpp
void handleApiAlloff(AsyncWebServerRequest *request) {
  manual_r = manual_g = manual_b = manual_w = 0;
  setAll(0, 0, 0, 0);
  strip.show();
  request->send(204);
}
```

- [ ] **Step 6: Convert handleApiPlay to flag-based**

Replace the entire function:
```cpp
void handleApiPlay(AsyncWebServerRequest *request) {
  if (!request->hasParam(F("anim"), true)) { request->send(400, F("text/plain"), F("anim=1..6")); return; }
  int anim = request->getParam(F("anim"), true)->value().toInt();
  if (anim < 1 || anim > 6) { request->send(400, F("text/plain"), F("anim 1..6")); return; }
  g_pendingPlayAnim = anim;
  request->send(204);
}
```

- [ ] **Step 7: Convert handleApiTime**

Replace the entire function with:
```cpp
void handleApiTime(AsyncWebServerRequest *request) {
  String json = "{\"date\":\"";
  if (g_lastNtpTime <= 0) {
    json += "--\",\"time\":\"--\"";
  } else {
    time_t t = (time_t)(g_lastNtpTime + TIMEZONE_OFFSET_SEC(g_lastNtpTime));
    struct tm *tm = gmtime(&t);
    if (!tm) {
      json += "--\",\"time\":\"--\"";
    } else {
      char buf[24];
      snprintf(buf, sizeof(buf), "%04d-%02d-%02d", tm->tm_year + 1900, tm->tm_mon + 1, tm->tm_mday);
      json += buf;
      json += "\",\"time\":\"";
      snprintf(buf, sizeof(buf), "%02d:%02d:%02d", tm->tm_hour, tm->tm_min, tm->tm_sec);
      json += buf;
    }
  }
  json += "\",\"uptime_ms\":";
  json += (unsigned long)millis();
  json += ",\"last_reboot\":\"";
  if (s_bootTimeUtc <= 0) {
    json += "--\"}";
  } else {
    time_t bt = (time_t)(s_bootTimeUtc + TIMEZONE_OFFSET_SEC(s_bootTimeUtc));
    struct tm *bm = gmtime(&bt);
    if (!bm) {
      json += "--\"}";
    } else {
      char buf[24];
      snprintf(buf, sizeof(buf), "%04d-%02d-%02d %02d:%02d:%02d",
               bm->tm_year + 1900, bm->tm_mon + 1, bm->tm_mday,
               bm->tm_hour, bm->tm_min, bm->tm_sec);
      json += buf;
      json += "\"}";
    }
  }
  AsyncWebServerResponse *response = request->beginResponse(200, F("application/json"), json);
  response->addHeader(F("Cache-Control"), F("no-store"));
  request->send(response);
}
```

- [ ] **Step 8: Convert handleApiReboot to flag-based**

Replace:
```cpp
void handleApiReboot() {
  if (server.method() != HTTP_POST) { server.send(405, F("text/plain"), F("Method Not Allowed")); return; }
  server.send(204);
  server.handleClient();
  delay(300);
  ESP.restart();
}
```
with:
```cpp
void handleApiReboot(AsyncWebServerRequest *request) {
  g_pendingReboot = true;
  request->send(204);
}
```

- [ ] **Step 9: Convert handleApiLog**

Replace the entire function with:
```cpp
void handleApiLog(AsyncWebServerRequest *request) {
  String json = "[";
  const char* animNames[] = { "", "Random fade", "Rainbow", "White ramp", "Star sparkle", "Birthday" };
  for (uint8_t i = 0; i < motionLogCount; i++) {
    int idx = (motionLogHead - 1 - i + MOTION_LOG_SIZE) % MOTION_LOG_SIZE;
    if (i > 0) json += ",";
    json += "{\"dir\":\""; json += motionLog[idx].dir;
    json += "\",\"anim\":\""; json += (motionLog[idx].anim_id <= 5) ? animNames[motionLog[idx].anim_id] : "";
    json += "\",\"time\":\"";
    if (motionLog[idx].timestamp <= 0) {
      json += "--:--";
    } else {
      time_t t = (time_t)(motionLog[idx].timestamp + TIMEZONE_OFFSET_SEC(motionLog[idx].timestamp));
      struct tm *tm = gmtime(&t);
      if (tm) {
        char buf[8];
        snprintf(buf, sizeof(buf), "%02d:%02d", tm->tm_hour, tm->tm_min);
        json += buf;
      } else json += "--:--";
    }
    json += "\"}";
  }
  json += "]";
  AsyncWebServerResponse *response = request->beginResponse(200, F("application/json"), json);
  response->addHeader(F("Cache-Control"), F("no-store"));
  request->send(response);
}
```

- [ ] **Step 10: Convert handleApiMemory**

Replace the entire function with:
```cpp
#ifndef ESP8266_HEAP_TOTAL
#define ESP8266_HEAP_TOTAL 80192u
#endif
void handleApiMemory(AsyncWebServerRequest *request) {
  uint32_t heapFree = ESP.getFreeHeap();
  uint32_t heapTotal = ESP8266_HEAP_TOTAL;
  uint32_t heapUsed = (heapTotal > heapFree) ? (heapTotal - heapFree) : 0;
  uint32_t heapPct = (heapTotal > 0) ? (heapUsed * 100 / heapTotal) : 0;
  uint8_t heapFrag = ESP.getHeapFragmentation();
  uint32_t heapMaxBlock = ESP.getMaxFreeBlockSize();
  uint32_t sketchSize = ESP.getSketchSize();
  uint32_t sketchFree = ESP.getFreeSketchSpace();
  uint32_t flashSize = ESP.getFlashChipSize();
  uint32_t flashUsed = sketchSize;
  uint32_t flashPct = (flashSize > 0) ? (flashUsed * 100 / flashSize) : 0;
  const uint32_t rtcTotal = 768u;
  uint32_t rtcUsed = 0;
  uint32_t rtcPct = 0;
  String json = "{\"heap_total\":";
  json += heapTotal;
  json += ",\"heap_used\":";
  json += heapUsed;
  json += ",\"heap_pct\":";
  json += heapPct;
  json += ",\"heap_free\":";
  json += heapFree;
  json += ",\"heap_frag\":";
  json += heapFrag;
  json += ",\"heap_max_block\":";
  json += heapMaxBlock;
  json += ",\"flash_size\":";
  json += flashSize;
  json += ",\"flash_used\":";
  json += flashUsed;
  json += ",\"flash_pct\":";
  json += flashPct;
  json += ",\"rtc_total\":";
  json += rtcTotal;
  json += ",\"rtc_used\":";
  json += rtcUsed;
  json += ",\"rtc_pct\":";
  json += rtcPct;
  json += ",\"sketch_free\":";
  json += sketchFree;
  json += "}";
  AsyncWebServerResponse *response = request->beginResponse(200, F("application/json"), json);
  response->addHeader(F("Cache-Control"), F("no-store"));
  request->send(response);
}
```

- [ ] **Step 11: Convert handleApiSysinfo**

Replace the entire function with:
```cpp
void handleApiSysinfo(AsyncWebServerRequest *request) {
  String ri = s_resetInfo;
  ri.replace("\"", "'");
  String json = "{\"cpu_mhz\":";
  json += ESP.getCpuFreqMHz();
  json += ",\"reset_reason\":\""; json += s_resetReason;     json += "\"";
  json += ",\"reset_info\":\"";   json += ri;                json += "\"";
  json += ",\"rssi\":";           json += WiFi.RSSI();
  json += ",\"ssid\":\"";         json += WiFi.SSID();       json += "\"";
  json += ",\"bssid\":\"";        json += WiFi.BSSIDstr();   json += "\"";
  json += ",\"ip\":\"";           json += WiFi.localIP().toString();      json += "\"";
  json += ",\"gateway\":\"";      json += WiFi.gatewayIP().toString();    json += "\"";
  json += ",\"dns\":\"";          json += WiFi.dnsIP().toString();        json += "\"";
  json += ",\"channel\":";        json += WiFi.channel();
  json += ",\"reconnects\":";     json += g_wifiReconnectCount;
  json += "}";
  AsyncWebServerResponse *response = request->beginResponse(200, F("application/json"), json);
  response->addHeader(F("Cache-Control"), F("no-store"));
  request->send(response);
}
```

- [ ] **Step 12: Commit**

```bash
git add rgbw_stair_light/rgbw_stair_light.ino
git commit -m "Phase 1b: Convert all request handlers to AsyncWebServer API"
```

---

### Task 3: Update route registration, loop() logic, and verify compilation

**Files:**
- Modify: `rgbw_stair_light/rgbw_stair_light.ino:676-689` (route registration in setup())
- Modify: `rgbw_stair_light/rgbw_stair_light.ino:723-837` (loop() — add pending anim/reboot checks)

- [ ] **Step 1: Update route registration in setup()**

Replace:
```cpp
  // Web server: frontend cacheable (GET /), API GET/POST
  server.on(F("/"), handleIndex);
  server.on(F("/index.html"), handleIndex);
  server.on(F("/api/state"), HTTP_GET, handleApiState);
  server.on(F("/api/auto"), HTTP_POST, handleApiAuto);
  server.on(F("/api/color"), HTTP_POST, handleApiColor);
  server.on(F("/api/alloff"), HTTP_POST, handleApiAlloff);
  server.on(F("/api/play"), HTTP_POST, handleApiPlay);
  server.on(F("/api/time"), HTTP_GET, handleApiTime);
  server.on(F("/api/reboot"), HTTP_POST, handleApiReboot);
  server.on(F("/api/log"), HTTP_GET, handleApiLog);
  server.on(F("/api/memory"),  HTTP_GET,  handleApiMemory);
  server.on(F("/api/sysinfo"), HTTP_GET,  handleApiSysinfo);
  server.onNotFound([]() { server.send(404, F("text/plain"), F("Not Found")); });
  server.begin();
```
with:
```cpp
  // Web server: frontend cacheable (GET /), API GET/POST (AsyncWebServer)
  server.on("/", HTTP_GET, handleIndex);
  server.on("/index.html", HTTP_GET, handleIndex);
  server.on("/api/state", HTTP_GET, handleApiState);
  server.on("/api/auto", HTTP_POST, handleApiAuto);
  server.on("/api/color", HTTP_POST, handleApiColor);
  server.on("/api/alloff", HTTP_POST, handleApiAlloff);
  server.on("/api/play", HTTP_POST, handleApiPlay);
  server.on("/api/time", HTTP_GET, handleApiTime);
  server.on("/api/reboot", HTTP_POST, handleApiReboot);
  server.on("/api/log", HTTP_GET, handleApiLog);
  server.on("/api/memory", HTTP_GET, handleApiMemory);
  server.on("/api/sysinfo", HTTP_GET, handleApiSysinfo);
  server.onNotFound([](AsyncWebServerRequest *request) { request->send(404, F("text/plain"), F("Not Found")); });
  server.begin();
```

Note: `AsyncWebServer::on()` takes plain `const char*` for paths (not `F()` macro). Method parameter is required for all routes.

- [ ] **Step 2: Add pending animation and reboot handling to loop()**

In the main `while (true)` loop in `loop()`, right after `ArduinoOTA.handle();` and `watchdogCount = 0;`, add:

```cpp
    // Handle pending reboot from web UI
    if (g_pendingReboot) {
      delay(300);
      ESP.restart();
    }

    // Handle pending animation from web UI
    if (g_pendingPlayAnim > 0) {
      int anim = g_pendingPlayAnim;
      g_pendingPlayAnim = 0;
      g_animDurationOverrideMs = 10000;
      if (anim == 6) {
        nightAnimation("UP");
        setAll(0, 0, 0, 0);
        strip.show();
      } else if (anim == 1) simpleFadeToRandom(F("UP"));
      else if (anim == 2) rainbowSteps(F("UP"));
      else if (anim == 3) FadeToFullBrightness(F("UP"));
      else if (anim == 4) starSparkle(F("UP"));
      else if (anim == 5) birthday(F("UP"));
      g_animDurationOverrideMs = 0;
      if (!automationOn) applyManualColor();
      else { setAll(0, 0, 0, 0); strip.show(); }
    }
```

- [ ] **Step 3: Compile**

```bash
arduino-cli compile --fqbn esp8266:esp8266:nodemcuv2 rgbw_stair_light/
```

Expected: clean compilation with no errors.

If there are errors, most likely causes:
- Missing `true` parameter in `hasParam`/`getParam` for POST body params
- Stray `server.` references not yet converted (search for `server.send`, `server.hasArg`, `server.arg`)

- [ ] **Step 4: Commit**

```bash
git add rgbw_stair_light/rgbw_stair_light.ino
git commit -m "Phase 1c: Update route registration and loop() for async handlers"
```

- [ ] **Step 5: Upload to ESP and test**

```bash
cd /Users/thomasstolt/Library/CloudStorage/OneDrive-Persoenlich/Documents/Github/Stair-Light-Project
./upload-to-esp8266-ota.sh
```

Verify all endpoints work:
- Open `http://<ESP-IP>/` — existing UI loads
- Automation On/Off buttons work
- RGBW +/- buttons work
- All-channel presets work
- Animation dropdown + Go plays the animation
- Reboot button reboots
- Motion log, memory, CPU, WiFi tables populate
- OTA upload works after reboot

- [ ] **Step 6: Commit any fixes**

If any fixes were needed:
```bash
git add rgbw_stair_light/rgbw_stair_light.ino rgbw_stair_light/parking.h
git commit -m "Phase 1: Fix issues found during hardware testing"
```

---

## Phase 2: Web UI Redesign

### Task 4: Rewrite the HTML/CSS in handleIndex

**Files:**
- Modify: `rgbw_stair_light/rgbw_stair_light.ino:209-293` (the PROGMEM HTML string in handleIndex)

- [ ] **Step 1: Replace the entire HTML string**

Replace the HTML PSTR string inside `handleIndex` (everything between `beginResponse_P(200, "text/html", PSTR(` and the closing `));`). The full replacement — note this does NOT include the `<script>` tag yet (that is Task 5):

```cpp
  AsyncWebServerResponse *response = request->beginResponse_P(200, "text/html", PSTR(
    "<!DOCTYPE html><html><head><meta charset=utf-8><meta name=viewport content=\"width=device-width,initial-scale=1\">"
    "<title>Stair Light</title><style>"
    "body{font-family:sans-serif;margin:0;background:#1a1a1a;color:#eee;display:flex;flex-direction:column;align-items:center;min-height:100vh;padding:1.5rem 1rem;box-sizing:border-box;}"
    "main{text-align:center;max-width:420px;width:100%;} h1{font-size:1.3rem;margin:0 0 1rem;}"
    ".section{background:#222;padding:0.8rem;border-radius:8px;margin-bottom:0.8rem;}"
    "button.btn{padding:0.7rem 1rem;border-radius:8px;font-size:1rem;cursor:pointer;border:1px solid rgba(0,0,0,0.25);min-height:2.4em;"
    "box-shadow:inset 0 1px 0 rgba(255,255,255,0.15),0 2px 4px rgba(0,0,0,0.3);text-shadow:0 1px 1px rgba(0,0,0,0.3);transition:box-shadow .1s,transform .1s;}"
    "button.btn:active{box-shadow:inset 0 2px 6px rgba(0,0,0,0.4);transform:translateY(1px);}"
    ".auto-on{background:linear-gradient(180deg,#3a5a3a,#1a3a1a);color:#9f9;}"
    ".auto-off{background:linear-gradient(180deg,#5a3a3a,#3a1a1a);color:#f99;}"
    ".preset{background:linear-gradient(180deg,#3a4a5c,#1a2a38);color:#8cf;padding:0.5rem 0.7rem;font-size:0.95rem;}"
    ".reboot{background:linear-gradient(180deg,#884422,#442200);color:#ffc;}"
    ".anim-btn{padding:0.6rem 0.8rem;font-size:0.9rem;border-radius:8px;cursor:pointer;border:1px solid rgba(0,0,0,0.25);"
    "box-shadow:inset 0 1px 0 rgba(255,255,255,0.15),0 2px 4px rgba(0,0,0,0.3);transition:box-shadow .1s,transform .1s;}"
    ".anim-btn:active{box-shadow:inset 0 2px 6px rgba(0,0,0,0.4);transform:translateY(1px);}"
    ".a1{background:linear-gradient(180deg,#3a5a3a,#1a3a1a);color:#9f9;}"
    ".a2{background:linear-gradient(180deg,#2a3a5a,#1a2a4a);color:#8cf;}"
    ".a3{background:linear-gradient(180deg,#4a4a4a,#2a2a2a);color:#eee;}"
    ".a4{background:linear-gradient(180deg,#1a2a4a,#0a1a3a);color:#88f;}"
    ".a5{background:linear-gradient(180deg,#5a3a5a,#3a1a3a);color:#f8f;}"
    ".a6{background:linear-gradient(180deg,#5a2a2a,#3a1a1a);color:#f88;}"
    ".led{width:12px;height:12px;border-radius:50%;display:inline-block;flex-shrink:0;box-shadow:0 0 6px currentColor;}"
    ".led-r{background:#e00;color:#e00;} .led-g{background:#0a0;color:#0a0;} .led-b{background:#06f;color:#06f;} .led-w{background:#eee;color:#eee;}"
    ".slider-row{display:flex;align-items:center;gap:8px;margin:6px 0;}"
    "input[type=range]{flex:1;height:6px;-webkit-appearance:none;appearance:none;background:#333;border-radius:3px;outline:none;}"
    "input[type=range]::-webkit-slider-thumb{-webkit-appearance:none;width:22px;height:22px;border-radius:50%;cursor:pointer;border:2px solid #555;}"
    ".sr input::-webkit-slider-thumb{background:#e00;} .sg input::-webkit-slider-thumb{background:#0a0;} .sb input::-webkit-slider-thumb{background:#06f;} .sw input::-webkit-slider-thumb{background:#eee;}"
    "span.pct{min-width:2.5em;text-align:right;font-size:0.9rem;}"
    ".row{display:flex;align-items:center;justify-content:center;gap:6px;margin:6px 0;flex-wrap:wrap;}"
    "table{width:100%;border-collapse:collapse;font-size:0.85rem;margin-top:0.3rem;} th,td{border:1px solid #444;padding:0.25rem 0.4rem;text-align:left;} th{background:#333;}"
    "details{background:#222;border-radius:8px;margin-bottom:0.5rem;} summary{padding:0.6rem 0.8rem;cursor:pointer;font-weight:bold;font-size:0.95rem;color:#aaa;}"
    "details[open] summary{color:#eee;} details .inner{padding:0 0.8rem 0.8rem;}"
    "</style></head><body><main>"
    "<h1>Stair Light</h1>"
    "<p style=margin-bottom:0.5rem;font-size:0.95rem;><span id=dateDisplay>--</span> <span id=timeDisplay>--</span></p>"
    "<p style=margin-bottom:0.3rem;font-size:0.85rem;>Uptime: <span id=uptimeDisplay>--</span> &nbsp; Last reboot: <span id=lastRebootDisplay>--</span></p>"
    "<div class=section>"
    "<b>Stair automation</b><br>"
    "<div class=row><button type=button class=\"btn auto-on\" id=autoOn>On</button>"
    "<button type=button class=\"btn auto-off\" id=autoOff>Off</button>"
    "<b id=autoStatus style=margin-left:0.3rem;>&ndash;</b></div>"
    "<p id=nightBadge style=\"display:none;margin:0.4rem 0 0;padding:0.4rem 0.8rem;border-radius:8px;background:rgba(180,40,40,0.25);border:1px solid #a33;font-size:0.9rem;color:#f88;\">Night mode active (" NIGHT_HOUR_START_STR ":00 &ndash; " NIGHT_HOUR_END_STR ":00)</p>"
    "</div>"
    "<div class=section>"
    "<b>RGBW Channels</b>"
    "<div class=\"slider-row sr\"><span class=\"led led-r\"></span><input type=range id=slR min=0 max=100 value=0><span id=pctR class=pct>0%</span></div>"
    "<div class=\"slider-row sg\"><span class=\"led led-g\"></span><input type=range id=slG min=0 max=100 value=0><span id=pctG class=pct>0%</span></div>"
    "<div class=\"slider-row sb\"><span class=\"led led-b\"></span><input type=range id=slB min=0 max=100 value=0><span id=pctB class=pct>0%</span></div>"
    "<div class=\"slider-row sw\"><span class=\"led led-w\"></span><input type=range id=slW min=0 max=100 value=0><span id=pctW class=pct>0%</span></div>"
    "<div class=row style=margin-top:0.5rem;><b style=margin-right:0.3rem;>All</b>"
    "<button type=button class=\"btn preset\" data-all=0>0%</button>"
    "<button type=button class=\"btn preset\" data-all=25>25%</button>"
    "<button type=button class=\"btn preset\" data-all=50>50%</button>"
    "<button type=button class=\"btn preset\" data-all=75>75%</button>"
    "<button type=button class=\"btn preset\" data-all=100>100%</button></div>"
    "</div>"
    "<div class=section>"
    "<b>Animations (10 s)</b>"
    "<div class=row style=margin-top:0.5rem;>"
    "<button type=button class=\"anim-btn a1\" data-anim=1>Random fade</button>"
    "<button type=button class=\"anim-btn a2\" data-anim=2>Rainbow</button>"
    "<button type=button class=\"anim-btn a3\" data-anim=3>White ramp</button>"
    "</div><div class=row>"
    "<button type=button class=\"anim-btn a4\" data-anim=4>Star sparkle</button>"
    "<button type=button class=\"anim-btn a5\" data-anim=5>Birthday</button>"
    "<button type=button class=\"anim-btn a6\" data-anim=6>Night red</button>"
    "</div></div>"
    "<p><button type=button class=\"btn reboot\" id=rebootBtn>Reboot</button></p>"
    "<details id=detailLog><summary>Last 5 motions</summary><div class=inner>"
    "<table><thead><tr><th>Time</th><th>Direction</th><th>Animation</th></tr></thead><tbody id=motionLogBody></tbody></table></div></details>"
    "<details id=detailMem><summary>Memory status</summary><div class=inner>"
    "<table><thead><tr><th>Type</th><th>Total</th><th>Used</th><th>Usage</th></tr></thead><tbody id=memoryBody></tbody></table></div></details>"
    "<details id=detailCpu><summary>CPU / Runtime</summary><div class=inner>"
    "<table><thead><tr><th>Key</th><th>Value</th></tr></thead><tbody id=cpuBody></tbody></table></div></details>"
    "<details id=detailWifi><summary>WiFi</summary><div class=inner>"
    "<table><thead><tr><th>Key</th><th>Value</th></tr></thead><tbody id=wifiBody></tbody></table></div></details>"
    "<p style=margin-top:1rem;font-size:0.75rem;color:#666;>Firmware v" FW_VERSION "</p></main>"
    "<script>"
    "/* JS added in Task 5 */"
    "</script></body></html>"
  ));
  response->addHeader(F("Cache-Control"), F("public, max-age=3600"));
  request->send(response);
```

- [ ] **Step 2: Compile to verify HTML syntax**

```bash
arduino-cli compile --fqbn esp8266:esp8266:nodemcuv2 rgbw_stair_light/
```

Expected: clean compilation. If errors, check for unescaped quotes or missing string concatenation.

- [ ] **Step 3: Commit**

```bash
git add rgbw_stair_light/rgbw_stair_light.ino
git commit -m "Phase 2a: Rewrite HTML with sliders, animation buttons, collapsible diagnostics"
```

---

### Task 5: Rewrite the JavaScript (polling, sliders, event handlers)

**Files:**
- Modify: `rgbw_stair_light/rgbw_stair_light.ino` (the `<script>` section inside the PROGMEM HTML)

- [ ] **Step 1: Replace the placeholder script with the full JavaScript**

Replace `"/* JS added in Task 5 */"` with the full JavaScript. The complete `<script>` block (replace the entire `"<script>"..."</script></body></html>"` lines):

```cpp
    "<script>"
    "var sliders={r:document.getElementById('slR'),g:document.getElementById('slG'),b:document.getElementById('slB'),w:document.getElementById('slW')};"
    "var pcts={r:document.getElementById('pctR'),g:document.getElementById('pctG'),b:document.getElementById('pctB'),w:document.getElementById('pctW')};"
    "var debounce={};"
    "function post(url,body){return fetch(url,{method:'POST',headers:{'Content-Type':'application/x-www-form-urlencoded'},body:body||''});}"
    "function loadFast(){"
    "Promise.all([fetch('/api/state').then(function(r){return r.json();}),fetch('/api/time').then(function(r){return r.json();})]).then(function(arr){"
    "var d=arr[0],t=arr[1];"
    "document.getElementById('autoStatus').textContent=d.auto?'On':'Off';"
    "document.getElementById('nightBadge').style.display=d.night?'block':'none';"
    "var ch=['r','g','b','w'];"
    "for(var i=0;i<4;i++){if(!debounce[ch[i]]){sliders[ch[i]].value=d[ch[i]];pcts[ch[i]].textContent=d[ch[i]]+'%';}}"
    "document.getElementById('dateDisplay').textContent=t.date||'--';"
    "document.getElementById('timeDisplay').textContent=t.time||'--';"
    "var ms=t.uptime_ms||0,dy=Math.floor(ms/86400000),h=Math.floor((ms%86400000)/3600000),m=Math.floor((ms%3600000)/60000);"
    "document.getElementById('uptimeDisplay').textContent=(dy>0?dy+'d ':'')+h+'h '+m+'m';"
    "document.getElementById('lastRebootDisplay').textContent=t.last_reboot||'--';"
    "});}"
    "function loadSlow(){"
    "var dl=document.getElementById('detailLog'),dm=document.getElementById('detailMem'),dc=document.getElementById('detailCpu'),dw=document.getElementById('detailWifi');"
    "var fetches=[],keys=[];"
    "if(dl.open){fetches.push(fetch('/api/log').then(function(r){return r.json();}));keys.push('log');}else{fetches.push(Promise.resolve(null));keys.push('log');}"
    "if(dm.open){fetches.push(fetch('/api/memory').then(function(r){return r.json();}));keys.push('mem');}else{fetches.push(Promise.resolve(null));keys.push('mem');}"
    "if(dc.open||dw.open){fetches.push(fetch('/api/sysinfo').then(function(r){return r.json();}));keys.push('sys');}else{fetches.push(Promise.resolve(null));keys.push('sys');}"
    "Promise.all(fetches).then(function(arr){"
    "var log=arr[0],mem=arr[1],sys=arr[2];"
    "if(log){"
    "var tb=document.getElementById('motionLogBody');tb.innerHTML='';"
    "for(var i=0;i<log.length;i++){var r=document.createElement('tr');r.innerHTML='<td>'+log[i].time+'</td><td>'+log[i].dir+'</td><td>'+log[i].anim+'</td>';tb.appendChild(r);}}"
    "if(mem){"
    "function fmt(n){return n>=1024?(n/1024).toFixed(1)+' KB':n+' B';}"
    "document.getElementById('memoryBody').innerHTML='<tr><td>Heap (RAM)</td><td>'+fmt(mem.heap_total)+'</td><td>'+fmt(mem.heap_used)+'</td><td>'+mem.heap_pct+'%</td></tr>"
    "<tr><td>Flash</td><td>'+fmt(mem.flash_size)+'</td><td>'+fmt(mem.flash_used)+'</td><td>'+mem.flash_pct+'%</td></tr>"
    "<tr><td>RTC</td><td>'+fmt(mem.rtc_total)+'</td><td>'+fmt(mem.rtc_used)+'</td><td>'+mem.rtc_pct+'%</td></tr>';}"
    "if(sys){"
    "var rsn=sys.reset_reason||'--';var exRow=(rsn.indexOf('xception')>=0)?'<tr><td>Exception info</td><td>'+sys.reset_info+'</td></tr>':'';"
    "document.getElementById('cpuBody').innerHTML='<tr><td>CPU freq</td><td>'+sys.cpu_mhz+' MHz</td></tr><tr><td>Reset reason</td><td>'+rsn+'</td></tr>'+exRow;"
    "function rssiQ(v){if(v>=-50)return 'Excellent';if(v>=-60)return 'Good';if(v>=-70)return 'Fair';return 'Poor';}"
    "var rssi=sys.rssi||0;"
    "document.getElementById('wifiBody').innerHTML='<tr><td>SSID</td><td>'+sys.ssid+'</td></tr><tr><td>BSSID</td><td>'+sys.bssid+'</td></tr><tr><td>IP</td><td>'+sys.ip+'</td></tr>"
    "<tr><td>Gateway</td><td>'+sys.gateway+'</td></tr><tr><td>DNS</td><td>'+sys.dns+'</td></tr><tr><td>Channel</td><td>'+sys.channel+'</td></tr>"
    "<tr><td>RSSI</td><td>'+rssi+' dBm ('+rssiQ(rssi)+')</td></tr><tr><td>Reconnects</td><td>'+sys.reconnects+'</td></tr>';}"
    "});}"
    "['r','g','b','w'].forEach(function(ch){"
    "sliders[ch].addEventListener('input',function(){"
    "pcts[ch].textContent=this.value+'%';"
    "debounce[ch]=true;clearTimeout(debounce[ch+'t']);"
    "debounce[ch+'t']=setTimeout(function(){post('/api/color','c='+ch+'&v='+sliders[ch].value).then(function(){debounce[ch]=false;});},100);"
    "});"
    "});"
    "document.getElementById('autoOn').onclick=function(){post('/api/auto','on=1').then(loadFast);};"
    "document.getElementById('autoOff').onclick=function(){post('/api/auto','on=0').then(loadFast);};"
    "document.querySelectorAll('.preset').forEach(function(btn){btn.onclick=function(){post('/api/color','all='+btn.getAttribute('data-all')).then(loadFast);};});"
    "document.querySelectorAll('.anim-btn').forEach(function(btn){btn.onclick=function(){post('/api/play','anim='+btn.getAttribute('data-anim'));};});"
    "document.getElementById('rebootBtn').onclick=function(){this.disabled=true;this.textContent='Rebooting...';post('/api/reboot').then(function(){setTimeout(function(){location.reload();},4000);});};"
    "loadFast();loadSlow();"
    "setInterval(loadFast,2000);"
    "setInterval(loadSlow,15000);"
    "</script></body></html>"
```

Key behaviors:
- `loadFast()` polls `/api/state` + `/api/time` every 2s
- `loadSlow()` polls `/api/log`, `/api/memory`, `/api/sysinfo` every 15s, but only when their `<details>` section is open (checks `.open` property)
- Slider `input` events are debounced at 100ms and use `POST /api/color` with `c=<channel>&v=<value>`
- During active slider dragging (`debounce[ch]` is true), `loadFast` skips updating that slider to prevent fighting with user input
- Preset buttons call `POST /api/color` with `all=<value>` then refresh via `loadFast`
- Animation buttons call `POST /api/play` with `anim=<1-6>`

- [ ] **Step 2: Compile**

```bash
arduino-cli compile --fqbn esp8266:esp8266:nodemcuv2 rgbw_stair_light/
```

Expected: clean compilation.

- [ ] **Step 3: Commit**

```bash
git add rgbw_stair_light/rgbw_stair_light.ino
git commit -m "Phase 2b: Add JavaScript for sliders, tiered polling, animation buttons"
```

---

### Task 6: Upload, test, and finalize

**Files:**
- Possibly modify: `rgbw_stair_light/rgbw_stair_light.ino` (bug fixes found during testing)

- [ ] **Step 1: Upload to ESP**

```bash
cd /Users/thomasstolt/Library/CloudStorage/OneDrive-Persoenlich/Documents/Github/Stair-Light-Project
./upload-to-esp8266-ota.sh
```

- [ ] **Step 2: Test the UI**

Open `http://<ESP-IP>/` in a mobile browser. Verify:

1. **Header**: date, time, uptime, last reboot display correctly
2. **Automation**: On/Off buttons toggle automation, status text updates
3. **Night mode badge**: shows/hides correctly based on time
4. **RGBW sliders**: dragging updates percentage label in real-time, LEDs respond
5. **Preset buttons**: 0/25/50/75/100% set all sliders and LEDs
6. **Animation buttons**: each triggers its animation for 10s
7. **Reboot button**: shows "Rebooting...", page reloads after ~4s
8. **Collapsible diagnostics**: all four sections expand/collapse, data loads when opened
9. **Polling**: state/time update every ~2s, diagnostics only when expanded
10. **PIR triggers**: walk past sensors, verify automation still works, motion log updates

- [ ] **Step 3: Update firmware version**

In `rgbw_stair_light/rgbw_stair_light.ino`, update:
```cpp
#define FW_VERSION "1.0.0"
```
to:
```cpp
#define FW_VERSION "2.0.0"
```

- [ ] **Step 4: Final commit**

```bash
git add rgbw_stair_light/rgbw_stair_light.ino
git commit -m "Phase 2: Complete UI redesign with AsyncWebServer, bump to v2.0.0"
```

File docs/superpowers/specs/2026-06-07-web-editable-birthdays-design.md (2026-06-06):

# Web-Editable Birthdays — Design

**Date:** 2026-06-07
**Component:** `rgbw_stair_light/rgbw_stair_light.ino` (+ `birthdays.h`, README, CHANGELOG)
**Status:** Approved

## Goal

Let the user view and edit the birthday list from the Web UI. Birthdays are currently
compile-time constants in the gitignored `birthdays.h`; this makes them runtime-editable
and persisted to flash, with a per-entry name shown in the UI.

## Decisions (from brainstorming)

- **Edit model:** edit the whole list in the UI, then one **Save** writes it atomically
  (replace-all). Add appends a blank row; × removes a row.
- **Name field:** each birthday stores an optional short name, shown in the UI to identify
  the entry. The name is **UI-only** — the birthday animation stays generic and does not
  use it.
- **Max count:** 20 birthdays.
- **Storage:** **separate EEPROM region** for birthdays (Approach A), independent of the
  existing `Settings` region. This preserves the hostname/night settings already saved on
  the device (no reset on upgrade).
- `birthdays.h` becomes the **default source only**, consistent with how the hostname and
  night-mode defaults work.

## Architecture

Single Arduino sketch. The settings persistence layer added in v2.1.0 stores a `Settings`
struct at EEPROM offset 0 (magic `STL1`, version 1). This feature adds a second,
independent EEPROM region for birthdays at a fixed offset, plus a GET/POST API and a Web
UI section. Async web handlers validate input and persist; `loop()`/`isBirthdayToday()`
read the runtime copy.

### Component 1 — EEPROM layout (small refactor)

- Define `EEPROM_SIZE` (1024 bytes) and use it in **every** `EEPROM.begin()` call,
  replacing the current `EEPROM.begin(sizeof(Settings))`. On the ESP8266 core, `begin()`
  re-reads the whole sector into the RAM buffer, so any handler that writes only its own
  region leaves the other region intact (read-from-flash, write-back-unchanged).
- Layout:
  - `EEPROM_SETTINGS_ADDR = 0` (existing `Settings`, unchanged: same struct, magic, and
    version — so existing saved settings survive this upgrade).
  - `EEPROM_BIRTHDAYS_ADDR = 128` (fixed offset; leaves headroom for `Settings` growth).
- New struct + global:
```c
#define BIRTHDAYS_MAX     20
#define BIRTHDAY_NAME_LEN 20          // includes null terminator (<=19 visible chars)
#define BIRTHDAYS_MAGIC   0x53544231u // 'STB1'
#define BIRTHDAYS_VERSION 1
struct BirthdayStore {
  uint32_t magic;
  uint8_t  version;
  uint8_t  count;                     // 0..BIRTHDAYS_MAX
  struct {
    uint8_t month;                    // 1..12
    uint8_t day;                      // 1..31
    char    name[BIRTHDAY_NAME_LEN];  // null-terminated, may be empty
  } items[BIRTHDAYS_MAX];
};
BirthdayStore g_birthdays;
```
- `loadBirthdays()`: `EEPROM.begin(EEPROM_SIZE)`, `EEPROM.get(EEPROM_BIRTHDAYS_ADDR, g_birthdays)`.
  If `magic`/`version` mismatch (first boot / blank / schema change), seed from the
  compile-time defaults in `birthdays.h` (`BIRTHDAY_COUNT`, `BIRTHDAYS[][2]`), with names
  set to empty strings, clamp count to `BIRTHDAYS_MAX`, set magic/version, and
  `saveBirthdays()`.
- `saveBirthdays()`: `EEPROM.begin(EEPROM_SIZE)`, `EEPROM.put(EEPROM_BIRTHDAYS_ADDR, g_birthdays)`,
  `EEPROM.commit()`.
- Estimated size: 6 + 20×22 = 446 bytes, well within `EEPROM_SIZE` and the 4096-byte sector.

**Interface:** `void loadBirthdays()`, `void saveBirthdays()`. Depends on `<EEPROM.h>`,
`birthdays.h`.

### Component 2 — Behaviour wiring

- `isBirthdayToday(long unixTimeUtc)` iterates `g_birthdays.items[0..g_birthdays.count]`
  comparing `month`/`day` against the current local date (same date math as today),
  instead of the static `BIRTHDAYS[]`.
- `loadBirthdays()` is called in `setup()` next to `loadSettings()`.
- The birthday animation (`birthday()` in `parking.h`) is unchanged and does not use names.
- `birthdays.h` is retained solely as the default seed for `loadBirthdays()`.

### Component 3 — API

- `GET /api/birthdays` → JSON array `[{"m":<1-12>,"d":<1-31>,"name":"<sanitised>"},...]`,
  `Cache-Control: no-store`. Names are sanitised for JSON (`"` → `'`; backslashes/control
  chars cannot occur because POST validation restricts the charset — see below).
- `POST /api/birthdays` — **replace-all**, `application/x-www-form-urlencoded` body with
  indexed params: `count=N`, then for `i` in `0..N-1`: `m<i>`, `d<i>`, `n<i>`
  (name URL-encoded by the browser). Validation:
  - `count` present, integer `0..BIRTHDAYS_MAX`; else `400`.
  - each `m<i>` `1..12`, each `d<i>` `1..31`; else `400`.
  - each `n<i>` length `0..19`; characters restricted to letters, digits, space, and
    `-` `_` `.` (keeps JSON output safe and avoids control chars); else `400`.
  - On any invalid field: `400 text/plain` with a short message, **no partial write**
    (build into a local temp, only commit to `g_birthdays` after all entries validate).
  - On success: update `g_birthdays`, `saveBirthdays()`, `204`.
- Routes registered in `setup()` next to the other `server.on(...)` calls.

### Component 4 — Web UI

- New collapsible `<details id=detailBirthdays>` "Birthdays" section (matching existing
  styling), containing a `<div id=bdayRows>` (one row per entry: month number input,
  day number input, name text input, and a × remove button), an **Add** button that
  appends a blank row (capped at `BIRTHDAYS_MAX`), a **Save** button, and a status span.
- JS:
  - `loadBirthdays()` fetches `/api/birthdays` and renders rows.
  - A `renderBdayRow(m,d,name)` helper creates a row with its × handler.
  - Save serialises all rows into the indexed body and POSTs; shows
    "Saving…/Saved/Invalid"; reloads on `204`.
  - Called once at page load (like `loadSettings()`).

### Component 5 — Version + docs

- Bump `FW_VERSION` to `2.2.0`.
- CHANGELOG `2.2.0` entry; README: document `GET/POST /api/birthdays` and the Birthdays UI;
  note birthdays are runtime-editable and `birthdays.h` is the first-boot default.

## Data flow

```
Boot → loadBirthdays() → g_birthdays (or defaults from birthdays.h) → isBirthdayToday()
Web UI Birthdays section → GET /api/birthdays → render rows
Save → POST /api/birthdays (count + m/d/n indexed) → validate → g_birthdays → saveBirthdays() → EEPROM region @128
```

## Error handling

- `loadBirthdays()` self-heals on magic/version mismatch or blank flash (re-seeds defaults
  and re-saves).
- POST rejects invalid input with `400` and writes nothing on failure (validate-then-commit).
- Name charset restriction guarantees valid JSON on GET.
- Separate EEPROM regions + full-sector re-read on each `begin()` prevent the settings and
  birthday regions from corrupting each other.

## Testing

No unit-test harness (firmware). Verification:
1. **Compile clean** (`arduino-cli compile --fqbn esp8266:esp8266:nodemcu rgbw_stair_light`).
2. **Manual on-device:** open Birthdays section → shows the 3 existing dates; add a name;
   add a row; remove a row; Save → `GET /api/birthdays` reflects it; reboot → persisted.
   Confirm a configured date still triggers the birthday animation. Confirm hostname/night
   settings saved previously are still intact after this upgrade.

## Out of scope (YAGNI)

- Using the name in the birthday animation or motion log.
- Per-entry immediate add/delete (replace-all on Save chosen instead).
- Year field / age calculation.
- Day-of-month validation per month (1–31 accepted uniformly, matching current behaviour).

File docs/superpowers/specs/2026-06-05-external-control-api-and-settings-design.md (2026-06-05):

# External Control API + Configurable Settings — Design

**Date:** 2026-06-05
**Component:** `rgbw_stair_light/rgbw_stair_light.ino` (+ `parking.h`, `credentials.h`)
**Status:** Approved

## Goal

Two related additions to the Stair Light firmware:

1. **External control API** — a simple HTTP endpoint another process on the LAN can
   call to drive the strip directly (red, red blinking, green dim-down), bypassing
   motion detection. Intended for a parking/garage-style signalling scenario where an
   external controller decides moment-to-moment what to show.
2. **Web-configurable settings** — expose hostname and night-mode parameters (enable
   toggle + start/end hours) in the web UI, persisted to flash so they survive reboot.

## Decisions (from brainstorming)

- **API shape:** independent commands, not one scripted sequence. The external process
  decides timing and sends each state when it wants.
- **Persistence:** persist hostname + night settings to flash (EEPROM emulation).
- **After green fade:** clear the override; normal behaviour resumes automatically —
  day automation if on, or night mode if currently within night hours.
- **Auth:** none. Trusted LAN only, matching the existing API.
- **Night controls:** enable toggle **and** editable start/end hours. When disabled,
  night mode never engages regardless of time.
- **Night time granularity:** whole hours (0–23), matching the existing `isNightMode`.

## Architecture

The firmware is a single Arduino sketch with helpers in `parking.h`. Async web handlers
set `volatile` flags consumed by the blocking `loop()` (existing pattern for animations
and reboot). This design follows the same pattern so timed/blocking effects run in
`loop()` and the web server stays responsive.

### Component 1 — Settings persistence (EEPROM)

A small versioned struct stored in the ESP8266 EEPROM (flash sector emulation):

```c
struct Settings {
  uint32_t magic;        // sentinel; detects blank / first boot
  uint8_t  version;      // struct version for future migrations
  char     hostname[32]; // null-terminated
  bool     nightEnabled;
  uint8_t  nightStart;   // hour 0–23 (inclusive)
  uint8_t  nightEnd;     // hour 0–23 (exclusive)
};
```

- `loadSettings()` — called early in `setup()`. `EEPROM.begin(sizeof(Settings))` then
  `EEPROM.get`. If `magic` does not match the expected sentinel (first boot or blank
  flash), populate the struct from the compiled-in defaults (`OTA_HOSTNAME`,
  `NIGHT_HOUR_START`, `NIGHT_HOUR_END`, `nightEnabled = true`) and call `saveSettings()`.
- `saveSettings()` — `EEPROM.put` + `EEPROM.commit()`.
- The existing `#define`s (`OTA_HOSTNAME`, `NIGHT_HOUR_START`, `NIGHT_HOUR_END`) remain
  as the **default** source only.

**Interface:** `void loadSettings()`, `void saveSettings()`. Depends on `<EEPROM.h>`.

### Component 2 — Runtime config variables

New globals, initialised by `loadSettings()`:

- `String g_hostname` (or `char[32]`)
- `bool g_nightEnabled`
- `uint8_t g_nightStart`
- `uint8_t g_nightEnd`

Changes:
- `isNightMode()` reads `g_nightEnabled`, `g_nightStart`, `g_nightEnd` instead of the
  `#define`s. Returns `false` immediately if `!g_nightEnabled`.
- In `setup()`: `WiFi.hostname(g_hostname.c_str())` before `WiFi.begin(...)` so the
  device registers its name via DHCP, and `ArduinoOTA.setHostname(g_hostname.c_str())`.
- Night-time / enable changes apply **immediately** (next `loop()` iteration reads the
  globals). Hostname changes take effect **on next reboot** (used at startup by
  WiFi/OTA/mDNS) — the UI states this.

### Component 3 — External-control state machine

State (file-scope):

```c
enum ExtMode { EXT_NONE, EXT_RED, EXT_RED_BLINK, EXT_GREEN_FADE };
volatile int  g_pendingExtCmd = 0; // 0=none, else maps to a command incl. "clear"
ExtMode       g_extMode = EXT_NONE;
bool          g_extActive = false;
unsigned long g_extStartMs = 0;    // for green_fade timing
unsigned long g_extBlinkMs = 0;    // for red_blink toggle timing
bool          g_extBlinkOn = false;
```

Behaviour, serviced each `loop()` iteration (non-blocking, `millis()`-based):

| state | behaviour |
|---|---|
| `red` | solid red at full brightness, held until next command; `g_extActive=true` |
| `red_blink`  | red toggles on/off every 500 ms; `g_extActive=true` |
| `green_fade` | green ramps full→off over ~30 000 ms, then LEDs off, `g_extActive=false` (normal resumes) |
| `clear` | LEDs off, `g_extActive=false`, `g_extMode=EXT_NONE` (normal resumes) |

- While `g_extActive` is true, `loop()` **skips both day and night motion triggers** and
  the night-idle clearing logic, so the external signal is never overridden by a PIR
  event. `ArduinoOTA.handle()` and the web server continue to run.
- Colour values use full red / green via the existing gamma table for consistency with
  other effects. The green fade computes
  `pct = 100 * (30000 - elapsed) / 30000` and applies the gamma-mapped green.
- A new `red`/`red_blink`/`green_fade` command issued while one is already active simply
  replaces the current mode.

### Component 4 — API endpoint `/api/ext`

`POST /api/ext` with form/query param `state`:
- Accepts `red`, `red_blink`, `green_fade`, `clear`.
- Validates `state`; unknown value → `400 text/plain`.
- Maps to `g_pendingExtCmd` and returns `204` (consistent with `/api/play`,
  `/api/reboot`). The actual effect runs in `loop()`.
- No authentication (trusted LAN).

### Component 5 — Web UI: Settings section + endpoints

New collapsible `<details>` "Settings" section (matching the existing diagnostics
styling) added to the embedded `PROGMEM` page:

- **Hostname:** text input + Save button, with an "applies after reboot" hint.
- **Night mode:** enable checkbox, start-hour input, end-hour input + Save button.
- The existing night badge text becomes dynamic, showing the configured hours.

New endpoints:
- `GET /api/settings` → `{"hostname":"...","night_enabled":0|1,"night_start":H,"night_end":H}`
  (`Cache-Control: no-store`).
- `POST /api/settings` → accepts any of `hostname`, `night_enabled`, `night_start`,
  `night_end`; validates (hostname length ≤ 31 and non-empty; hours 0–23); updates the
  runtime globals; calls `saveSettings()`; returns `204` (or `400` on invalid input).

Route registration added in `setup()` next to the existing `server.on(...)` calls.

## Data flow

```
External process ──POST /api/ext state=red───────────► handler sets g_pendingExtCmd ─► loop() drives strip
Web UI ──POST /api/settings──► handler validates ─► updates g_* globals ─► saveSettings() ─► EEPROM
Boot ──► loadSettings() ─► g_* globals ─► WiFi.hostname / ArduinoOTA.setHostname / isNightMode()
```

## Error handling

- `loadSettings()` falls back to compiled defaults on magic/version mismatch and
  re-saves, so corrupt/blank flash self-heals.
- `/api/ext` and `/api/settings` reject invalid params with `400` and a short message.
- Hostname validation prevents empty or over-length values from being stored.
- External override never blocks OTA or the web server (effects are non-blocking in
  `loop()`).

## Testing

No unit-test harness exists for this firmware. Verification is:

1. **Compile clean** (arduino-cli / PlatformIO), no warnings introduced.
2. **External API (manual, `curl`):** each `state=red|red_blink|green_fade|clear`
   produces the expected LED behaviour; confirm the ~30 s green dim-down and that
   motion is ignored while active; confirm normal behaviour (incl. night mode) resumes
   after fade/clear.
3. **Settings (manual):** change night enable/start/end in the UI → takes effect
   immediately; change hostname → save, reboot, confirm new hostname on the router and
   for OTA; confirm all values **persist across reboot**.

## Out of scope (YAGNI)

- Authentication / tokens on the API.
- Minute-level night-time precision (whole hours only).
- LittleFS/JSON config (EEPROM struct is sufficient for these few values).
- A scripted single-call sequence (commands are independent).

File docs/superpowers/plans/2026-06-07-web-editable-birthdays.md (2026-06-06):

# Web-Editable Birthdays Implementation Plan

> **For agentic workers:** REQUIRED SUB-SKILL: Use superpowers:subagent-driven-development (recommended) or superpowers:executing-plans to implement this plan task-by-task. Steps use checkbox (`- [ ]`) syntax for tracking.

**Goal:** Let the user view and edit the birthday list (month, day, optional name) from the Web UI, persisted to a dedicated EEPROM region, with `birthdays.h` as the first-boot default.

**Architecture:** Single Arduino sketch. A new `BirthdayStore` struct lives in its own EEPROM region (offset 128), independent of the existing `Settings` region (offset 0) so saved settings survive the upgrade. Async handlers validate + persist; `isBirthdayToday()` reads the runtime copy. New `GET/POST /api/birthdays` and a Web UI "Birthdays" section.

**Tech Stack:** ESP8266 Arduino core, ESPAsyncWebServer, `<EEPROM.h>`, arduino-cli.

---

## Testing approach (read first)

No unit-test harness (firmware, can't run off-device). Each task's gate is a **clean compile**:
```
cd "/Users/tstolt/Library/CloudStorage/OneDrive-Persönlich/Documents/Github/Stair-Light-Project" && "/Applications/Arduino IDE.app/Contents/Resources/app/lib/backend/resources/arduino-cli" compile --fqbn esp8266:esp8266:nodemcu rgbw_stair_light
```
A clean compile ends with memory-usage tables and no error lines. The baseline compiles cleanly today, so any error after an edit is from that edit. On-device `curl`/browser checks are done by the human after merge. Commit only the files named in each task — the working tree has unrelated `build_minimal/` artifacts; never stage those.

---

## File structure

- **Modify** `rgbw_stair_light/rgbw_stair_light.ino` — all firmware changes (EEPROM region + struct, persistence fns, `isBirthdayToday()` wiring, two API handlers + routes, Web UI section + JS, version bump). Single-sketch project; follows the established pattern.
- **Modify** `CHANGELOG.md`, `README.md` — docs.
- `rgbw_stair_light/birthdays.h` — unchanged; retained as the default seed (gitignored).

---

## Task 1: Birthday EEPROM region + persistence

**Files:**
- Modify: `rgbw_stair_light/rgbw_stair_light.ino` (EEPROM size/offset defines; widen existing `EEPROM.begin` calls; `BirthdayStore` struct + load/save; call `loadBirthdays()` in `setup()`)

- [ ] **Step 1: Add EEPROM layout defines before the Settings block**

Find this line (currently ~183):
```cpp
#define SETTINGS_MAGIC   0x53544C31u  // 'STL1'
```
Insert immediately BEFORE it:
```cpp
// EEPROM is shared: Settings at offset 0, birthdays at a fixed offset further in.
#define EEPROM_SIZE            1024
#define EEPROM_BIRTHDAYS_ADDR  128   // Settings live at offset 0; leave headroom to grow
```

- [ ] **Step 2: Widen the two existing `EEPROM.begin` calls**

In `saveSettings()` change:
```cpp
  EEPROM.begin(sizeof(Settings));   // idempotent; makes saveSettings() safe to call standalone
```
to:
```cpp
  EEPROM.begin(EEPROM_SIZE);   // idempotent; makes saveSettings() safe to call standalone
```
In `loadSettings()` change:
```cpp
  EEPROM.begin(sizeof(Settings));
  EEPROM.get(0, g_settings);
```
to:
```cpp
  EEPROM.begin(EEPROM_SIZE);
  EEPROM.get(0, g_settings);
```

- [ ] **Step 3: Add the BirthdayStore struct + load/save functions**

Find the end of `loadSettings()` — the closing brace followed by a blank line, just before the `WiFiUDP udp;` line (currently ~216). Insert AFTER `loadSettings()`'s closing brace:
```cpp
// ---- Persistent birthdays (separate EEPROM region) ------------------------
// Independent magic/version so it self-heals without touching the Settings
// region. Seeded from the compile-time birthdays.h list on first boot.
#define BIRTHDAYS_MAX     20
#define BIRTHDAY_NAME_LEN 20            // includes null terminator (<=19 visible chars)
#define BIRTHDAYS_MAGIC   0x53544231u   // 'STB1'
#define BIRTHDAYS_VERSION 1
struct BirthdayStore {
  uint32_t magic;
  uint8_t  version;
  uint8_t  count;                       // 0..BIRTHDAYS_MAX
  struct {
    uint8_t month;                      // 1..12
    uint8_t day;                        // 1..31
    char    name[BIRTHDAY_NAME_LEN];    // null-terminated, may be empty
  } items[BIRTHDAYS_MAX];
};
BirthdayStore g_birthdays;

void saveBirthdays() {
  EEPROM.begin(EEPROM_SIZE);
  EEPROM.put(EEPROM_BIRTHDAYS_ADDR, g_birthdays);
  EEPROM.commit();
}

void loadBirthdays() {
  EEPROM.begin(EEPROM_SIZE);
  EEPROM.get(EEPROM_BIRTHDAYS_ADDR, g_birthdays);
  if (g_birthdays.magic != BIRTHDAYS_MAGIC || g_birthdays.version != BIRTHDAYS_VERSION) {
    // First boot / blank / schema change → seed from compiled birthdays.h defaults
    g_birthdays.magic   = BIRTHDAYS_MAGIC;
    g_birthdays.version = BIRTHDAYS_VERSION;
    uint8_t n = (BIRTHDAY_COUNT > BIRTHDAYS_MAX) ? BIRTHDAYS_MAX : (uint8_t)BIRTHDAY_COUNT;
    g_birthdays.count = n;
    for (uint8_t i = 0; i < n; i++) {
      g_birthdays.items[i].month   = BIRTHDAYS[i][0];
      g_birthdays.items[i].day     = BIRTHDAYS[i][1];
      g_birthdays.items[i].name[0] = '\0';
    }
    saveBirthdays();
  }
}
```

- [ ] **Step 4: Call `loadBirthdays()` in `setup()`**

Find this line in `setup()` (currently ~853):
```cpp
  loadSettings();
```
Change it to:
```cpp
  loadSettings();
  loadBirthdays();
```

- [ ] **Step 5: Compile-verify**

Run the compile command. Expected: clean (new symbols unused so far is fine; Task 2 wires `isBirthdayToday()`).

- [ ] **Step 6: Commit**

```bash
cd "/Users/tstolt/Library/CloudStorage/OneDrive-Persönlich/Documents/Github/Stair-Light-Project"
git add rgbw_stair_light/rgbw_stair_light.ino
git commit -m "Add EEPROM-backed birthday store (separate region, seeded from birthdays.h)"
```

---

## Task 2: Drive isBirthdayToday() from the runtime store

**Files:**
- Modify: `rgbw_stair_light/rgbw_stair_light.ino` (`isBirthdayToday()`)

- [ ] **Step 1: Replace the function body**

Replace the whole `isBirthdayToday()` function (currently ~672–684) with:
```cpp
bool isBirthdayToday(long unixTimeUtc) {
  if (g_birthdays.count == 0) return false;
  time_t t = (time_t)(unixTimeUtc + TIMEZONE_OFFSET_SEC(unixTimeUtc));
  struct tm *tm = gmtime(&t);
  if (!tm) return false;
  int month = tm->tm_mon + 1;
  int day = tm->tm_mday;
  for (uint8_t i = 0; i < g_birthdays.count; i++) {
    if ((int)g_birthdays.items[i].month == month && (int)g_birthdays.items[i].day == day)
      return true;
  }
  return false;
}
```

- [ ] **Step 2: Compile-verify**

Run the compile command. Expected: clean.

- [ ] **Step 3: Commit**

```bash
cd "/Users/tstolt/Library/CloudStorage/OneDrive-Persönlich/Documents/Github/Stair-Light-Project"
git add rgbw_stair_light/rgbw_stair_light.ino
git commit -m "Use runtime birthday store in isBirthdayToday()"
```

---

## Task 3: GET + POST /api/birthdays

**Files:**
- Modify: `rgbw_stair_light/rgbw_stair_light.ino` (two handlers + two routes)

- [ ] **Step 1: Add both handlers**

Add immediately AFTER `handleApiSettingsPost(...)`'s closing brace (the function currently starts ~728; insert after its final `}`):
```cpp
// GET /api/birthdays – JSON array of {m,d,name} for the Web UI
void handleApiBirthdaysGet(AsyncWebServerRequest *request) {
  String json = "[";
  for (uint8_t i = 0; i < g_birthdays.count; i++) {
    if (i > 0) json += ",";
    String nm = g_birthdays.items[i].name;
    nm.replace("\"", "'");
    json += "{\"m\":"; json += g_birthdays.items[i].month;
    json += ",\"d\":"; json += g_birthdays.items[i].day;
    json += ",\"name\":\""; json += nm; json += "\"}";
  }
  json += "]";
  AsyncWebServerResponse *response = request->beginResponse(200, F("application/json"), json);
  response->addHeader(F("Cache-Control"), F("no-store"));
  request->send(response);
}

// POST /api/birthdays – replace the whole list.
// Body (form-encoded): count=N then for i in 0..N-1: m<i>, d<i>, n<i>
void handleApiBirthdaysPost(AsyncWebServerRequest *request) {
  if (!request->hasParam(F("count"), true)) {
    request->send(400, F("text/plain"), F("count required")); return;
  }
  int count = request->getParam(F("count"), true)->value().toInt();
  if (count < 0 || count > BIRTHDAYS_MAX) {
    request->send(400, F("text/plain"), F("count 0..20")); return;
  }
  // Build into a static temp; only commit to g_birthdays after all entries validate
  // (no partial write). static avoids ~450 B on the async callback stack.
  static BirthdayStore tmp;
  tmp.magic   = BIRTHDAYS_MAGIC;
  tmp.version = BIRTHDAYS_VERSION;
  tmp.count   = (uint8_t)count;
  for (int i = 0; i < count; i++) {
    String mi = String("m") + i, di = String("d") + i, ni = String("n") + i;
    if (!request->hasParam(mi, true) || !request->hasParam(di, true)) {
      request->send(400, F("text/plain"), F("missing m/d for an entry")); return;
    }
    int m = request->getParam(mi, true)->value().toInt();
    int d = request->getParam(di, true)->value().toInt();
    if (m < 1 || m > 12) { request->send(400, F("text/plain"), F("month 1..12")); return; }
    if (d < 1 || d > 31) { request->send(400, F("text/plain"), F("day 1..31")); return; }
    String nm = request->hasParam(ni, true) ? request->getParam(ni, true)->value() : String("");
    nm.trim();
    if (nm.length() > BIRTHDAY_NAME_LEN - 1) {
      request->send(400, F("text/plain"), F("name too long (max 19)")); return;
    }
    for (size_t k = 0; k < nm.length(); k++) {
      char c = nm[k];
      bool ok = (c >= 'a' && c <= 'z') || (c >= 'A' && c <= 'Z') ||
                (c >= '0' && c <= '9') || c == ' ' || c == '-' || c == '_' || c == '.';
      if (!ok) { request->send(400, F("text/plain"), F("name: letters/digits/space/-_. only")); return; }
    }
    tmp.items[i].month = (uint8_t)m;
    tmp.items[i].day   = (uint8_t)d;
    strncpy(tmp.items[i].name, nm.c_str(), BIRTHDAY_NAME_LEN - 1);
    tmp.items[i].name[BIRTHDAY_NAME_LEN - 1] = '\0';
  }
  g_birthdays = tmp;
  saveBirthdays();
  request->send(204);
}
```

- [ ] **Step 2: Register the routes**

Find these lines in `setup()` (currently ~952–953):
```cpp
  server.on("/api/settings", HTTP_GET,  handleApiSettingsGet);
  server.on("/api/settings", HTTP_POST, handleApiSettingsPost);
```
Insert immediately AFTER them:
```cpp
  server.on("/api/birthdays", HTTP_GET,  handleApiBirthdaysGet);
  server.on("/api/birthdays", HTTP_POST, handleApiBirthdaysPost);
```

- [ ] **Step 3: Compile-verify**

Run the compile command. Expected: clean.

- [ ] **Step 4: Commit**

```bash
cd "/Users/tstolt/Library/CloudStorage/OneDrive-Persönlich/Documents/Github/Stair-Light-Project"
git add rgbw_stair_light/rgbw_stair_light.ino
git commit -m "Add GET/POST /api/birthdays (replace-all, validated, persisted)"
```

---

## Task 4: Web UI Birthdays section

**Files:**
- Modify: `rgbw_stair_light/rgbw_stair_light.ino` (`handleIndex()` PROGMEM HTML + JS)

Reminder: each inserted line is a separate quoted C string concatenated by the compiler. Any `"` inside the HTML/JS must be escaped `\"`; single-quoted JS strings need no escaping. Compile after each step to catch a broken literal early. The Add/Save buttons use `class="btn preset"`, which is safe — the color-preset click handler is scoped to `.preset[data-all]` and these have no `data-all`.

- [ ] **Step 1: Add the Birthdays section HTML**

Find the firmware-version footer line (currently ~344):
```cpp
    "<p style=margin-top:1rem;font-size:0.75rem;color:#666;>Firmware v" FW_VERSION "</p></main>"
```
Insert the following block IMMEDIATELY BEFORE that footer line:
```cpp
    "<details id=detailBirthdays><summary>Birthdays</summary><div class=inner>"
    ""
    "<div class=row style=justify-content:flex-start;margin-top:0.5rem;>"
    "<button type=button class=\"btn preset\" id=bdayAdd>+ Add</button>"
    "<button type=button class=\"btn preset\" id=bdaySave>Save</button>"
    "<span id=bdayStatus style=font-size:0.85rem;></span></div>"
    "</div></details>"
```
Compile.

- [ ] **Step 2: Add the Birthdays JavaScript**

Find the init line (currently ~418):
```cpp
    "loadFast();loadSlow();loadSettings();"
```
Insert the following block IMMEDIATELY BEFORE that init line:
```cpp
    "var BDAY_MAX=20;"
    "function bdayRow(m,d,name){"
    "var div=document.createElement('div');div.className='slider-row';div.style.gap='6px';"
    "div.innerHTML='<input type=number min=1 max=12 class=bm style=\"width:3.2em;background:#111;color:#eee;border:1px solid #444;border-radius:6px;padding:0.3rem;\"> '"
    "+'<input type=number min=1 max=31 class=bd style=\"width:3.2em;background:#111;color:#eee;border:1px solid #444;border-radius:6px;padding:0.3rem;\"> '"
    "+'<input type=text class=bn placeholder=name style=\"flex:1;min-width:0;background:#111;color:#eee;border:1px solid #444;border-radius:6px;padding:0.3rem;\"> '"
    "+'<button type=button class=btn style=\"padding:0.2rem 0.6rem;background:#522;color:#f99;\">x</button>';"
    "div.querySelector('.bm').value=m;div.querySelector('.bd').value=d;div.querySelector('.bn').value=name||'';"
    "div.querySelector('button').onclick=function(){div.remove();};"
    "return div;}"
    "function loadBirthdays(){"
    "fetch('/api/birthdays').then(function(r){return r.json();}).then(function(a){"
    "var box=document.getElementById('bdayRows');box.innerHTML='';"
    "for(var i=0;i<a.length;i++){box.appendChild(bdayRow(a[i].m,a[i].d,a[i].name));}"
    "});}"
    "document.getElementById('bdayAdd').onclick=function(){"
    "var box=document.getElementById('bdayRows');if(box.children.length>=BDAY_MAX)return;box.appendChild(bdayRow('','',''));};"
    "document.getElementById('bdaySave').onclick=function(){"
    "var rows=document.getElementById('bdayRows').children;var body='count='+rows.length;"
    "for(var i=0;i<rows.length;i++){"
    "body+='&m'+i+'='+encodeURIComponent(rows[i].querySelector('.bm').value)"
    "+'&d'+i+'='+encodeURIComponent(rows[i].querySelector('.bd').value)"
    "+'&n'+i+'='+encodeURIComponent(rows[i].querySelector('.bn').value);}"
    "var st=document.getElementById('bdayStatus');st.textContent='Saving...';st.style.color='#fc8';"
    "post('/api/birthdays',body).then(function(r){"
    "if(r.status===204){st.textContent='Saved';st.style.color='#9f9';loadBirthdays();}"
    "else{st.textContent='Invalid';st.style.color='#f88';}"
    "});};"
```
Compile.

- [ ] **Step 3: Call `loadBirthdays()` on page load**

Change the init line from:
```cpp
    "loadFast();loadSlow();loadSettings();"
```
to:
```cpp
    "loadFast();loadSlow();loadSettings();loadBirthdays();"
```

- [ ] **Step 4: Compile-verify**

Run the compile command. Expected: clean.

- [ ] **Step 5: Commit**

```bash
cd "/Users/tstolt/Library/CloudStorage/OneDrive-Persönlich/Documents/Github/Stair-Light-Project"
git add rgbw_stair_light/rgbw_stair_light.ino
git commit -m "Add web UI Birthdays section (list/add/remove/save)"
```

---

## Task 5: Version bump + documentation

**Files:**
- Modify: `rgbw_stair_light/rgbw_stair_light.ino` (`FW_VERSION`), `CHANGELOG.md`, `README.md`

- [ ] **Step 1: Bump the firmware version**

Change (currently ~169):
```cpp
#define FW_VERSION "2.1.0"
```
to:
```cpp
#define FW_VERSION "2.2.0"
```

- [ ] **Step 2: Add a CHANGELOG entry**

Insert at the top of `CHANGELOG.md`, directly under the `# Changelog` heading (newest entry), with a blank line after it:
```markdown
## 2.2.0 – 2026-06-07

- **Web-editable birthdays** – View and edit the birthday list (month, day, optional name) in the web UI under "Birthdays"; add/remove rows and Save. Each birthday can have a short name shown in the UI.
- **Persistent birthdays** – Birthdays are stored in a dedicated EEPROM region (separate from settings) and survive reboot; `birthdays.h` is now only the first-boot default. Up to 20 entries.
- **New endpoints** – `GET`/`POST /api/birthdays`.
```

- [ ] **Step 3: Document in README.md**

In `README.md`, find the `## External control API` section heading (added in 2.1.0). Insert the following NEW section immediately BEFORE it (leave a blank line after the new section, before `## External control API`):
```markdown
## Birthdays

Birthdays (month, day, and an optional name) trigger the birthday animation on the day.
They are editable in the web UI under **Birthdays** — add or remove rows and click Save —
and are stored in flash (up to 20 entries), surviving reboots. `birthdays.h` is only the
first-boot default; after that the saved list is authoritative.

API:

```bash
curl http://<host>/api/birthdays
# [{"m":11,"d":19,"name":"Anna"}, ...]
```

`POST /api/birthdays` replaces the whole list (form-encoded: `count=N` then `m<i>`,
`d<i>`, `n<i>` for each entry). Months 1–12, days 1–31, names up to 19 characters
(letters, digits, space, `-` `_` `.`).

```

- [ ] **Step 4: Compile-verify**

Run the compile command. Expected: clean (footer now v2.2.0).

- [ ] **Step 5: Commit**

```bash
cd "/Users/tstolt/Library/CloudStorage/OneDrive-Persönlich/Documents/Github/Stair-Light-Project"
git add rgbw_stair_light/rgbw_stair_light.ino CHANGELOG.md README.md
git commit -m "Bump to 2.2.0; document web-editable birthdays"
```

---

## Self-review checklist (completed by plan author)

- **Spec coverage:** separate EEPROM region @128 + EEPROM_SIZE widen (Task 1) ✓; BirthdayStore struct with name[20], max 20, magic/version self-heal seeded from birthdays.h (Task 1) ✓; isBirthdayToday uses g_birthdays (Task 2) ✓; GET returns {m,d,name} sanitised + no-store (Task 3) ✓; POST replace-all, indexed params, validation (count 0–20, month 1–12, day 1–31, name ≤19 + charset), validate-then-commit no partial write (Task 3) ✓; routes registered (Task 3) ✓; Web UI list/add/remove/save section + JS + load on page load (Task 4) ✓; FW_VERSION 2.2.0 + docs (Task 5) ✓; settings region untouched (Settings struct/magic/version unchanged; only begin size widened) ✓; name UI-only, animation unchanged ✓.
- **Placeholder scan:** none — all steps contain concrete code/commands.
- **Type/name consistency:** `g_birthdays`, `BirthdayStore`, `BIRTHDAYS_MAX`, `BIRTHDAY_NAME_LEN`, `BIRTHDAYS_MAGIC`/`BIRTHDAYS_VERSION`, `EEPROM_SIZE`, `EEPROM_BIRTHDAYS_ADDR`, `loadBirthdays`/`saveBirthdays`, `handleApiBirthdaysGet`/`handleApiBirthdaysPost` used consistently; JSON keys `m`/`d`/`name` match between GET output, JS reader, and POST param names `m<i>`/`d<i>`/`n<i>`; reuses existing `setAll`/`post()`/`.slider-row`/`.preset[data-all]` correctly.
```

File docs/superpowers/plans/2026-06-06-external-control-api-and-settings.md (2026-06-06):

# External Control API + Configurable Settings — Implementation Plan

> **For agentic workers:** REQUIRED SUB-SKILL: Use superpowers:subagent-driven-development (recommended) or superpowers:executing-plans to implement this plan task-by-task. Steps use checkbox (`- [ ]`) syntax for tracking.

**Goal:** Add an HTTP API for an external LAN process to drive the LED strip directly (red, red blinking, green dim-down), and make hostname + night-mode settings web-configurable and persisted to flash.

**Architecture:** Single Arduino sketch (`rgbw_stair_light/rgbw_stair_light.ino`) with helpers in `parking.h`. Async web handlers set `volatile` flags consumed by the blocking `loop()` (existing pattern). Settings live in a versioned struct persisted via ESP8266 EEPROM emulation; the struct fields ARE the runtime config (no separate globals — DRY). An external-control state machine runs non-blocking in `loop()` and suppresses motion triggers while active.

**Tech Stack:** ESP8266 Arduino core, ESPAsyncWebServer, Adafruit NeoPixel, `<EEPROM.h>` (core library), `arduino-cli`.

---

## Testing approach (read first)

This firmware has **no unit-test harness** and cannot be unit-tested off-device. Standard TDD does not apply. Each task therefore uses this loop instead:

1. Make the edit (exact code given).
2. **Compile-verify** — the project must compile clean:
   ```bash
   arduino-cli compile --fqbn esp8266:esp8266:nodemcu rgbw_stair_light
   ```
   (Run from the repo root. Equivalent to the VS Code task "Arduino: Compile (ESP8266 NodeMCU)". If `arduino-cli` is not on your PATH in a plain shell, run it from the VS Code task or your interactive shell.)
   Expected: `Sketch uses ... bytes` with no errors.
3. **Manual on-device verification** (where noted) — upload via `./upload-to-esp8266-ota.sh <host>` and check behaviour with `curl` / browser.
4. **Commit.**

Commit only the source/docs files named in each task — the working tree contains many unrelated `build_minimal/` artifacts; do **not** stage those.

---

## File structure

- **Modify** `rgbw_stair_light/rgbw_stair_light.ino` — all firmware changes (persistence, runtime config use, external-control state machine, new API handlers, route registration, web UI, version bump). This is the project's single sketch file; following the established all-in-one pattern.
- **Modify** `CHANGELOG.md` — new version entry.
- **Modify** `README.md` — document the external API and web-configurable settings.

No new files: the project deliberately keeps everything in the sketch + `parking.h`, and the new code is cohesive with existing handlers.

---

## Task 1: Settings persistence layer (EEPROM)

**Files:**
- Modify: `rgbw_stair_light/rgbw_stair_light.ino` (add `#include <EEPROM.h>`; add struct + globals + load/save after the `#include "parking.h"` line; call `loadSettings()` in `setup()`)

- [ ] **Step 1: Add the EEPROM include**

In `rgbw_stair_light.ino`, add the include next to the other includes (after line `#include <Ticker.h>`):

```cpp
#include <Ticker.h>
#include <EEPROM.h>
#include <time.h>
```

- [ ] **Step 2: Add the Settings struct, global, and load/save functions**

Immediately **after** the `#include "parking.h"` line (currently line 168), add:

```cpp
// ---- Persistent settings (EEPROM emulation) -------------------------------
// A small versioned struct. On first boot / blank flash / version change we
// fall back to the compiled-in defaults and re-save. The struct fields are the
// runtime config (read directly elsewhere) – no separate shadow globals.
#define SETTINGS_MAGIC   0x53544C31u  // 'STL1'
#define SETTINGS_VERSION 1
struct Settings {
  uint32_t magic;
  uint8_t  version;
  char     hostname[32];   // null-terminated, <=31 chars
  bool     nightEnabled;
  uint8_t  nightStart;     // hour 0–23 (inclusive)
  uint8_t  nightEnd;       // hour 0–23 (exclusive)
};
Settings g_settings;

void saveSettings() {
  EEPROM.put(0, g_settings);
  EEPROM.commit();
}

void loadSettings() {
  EEPROM.begin(sizeof(Settings));
  EEPROM.get(0, g_settings);
  if (g_settings.magic != SETTINGS_MAGIC || g_settings.version != SETTINGS_VERSION) {
    // First boot / blank / version mismatch → compiled defaults
    g_settings.magic   = SETTINGS_MAGIC;
    g_settings.version = SETTINGS_VERSION;
    strncpy(g_settings.hostname, OTA_HOSTNAME, sizeof(g_settings.hostname) - 1);
    g_settings.hostname[sizeof(g_settings.hostname) - 1] = '\0';
    g_settings.nightEnabled = true;
    g_settings.nightStart   = NIGHT_HOUR_START;
    g_settings.nightEnd     = NIGHT_HOUR_END;
    saveSettings();
  }
}
```

(`saveSettings` is defined before `loadSettings`; in an `.ino` file function order does not matter because the Arduino preprocessor auto-prototypes, but this order also satisfies a plain C reading.)

- [ ] **Step 3: Call `loadSettings()` early in `setup()`**

In `setup()`, right after the reset-info caching lines:

```cpp
  // Cache reset reason/info before WiFi stack overwrites them
  s_resetReason = ESP.getResetReason();
  s_resetInfo   = ESP.getResetInfo();

  // Load persisted settings (hostname, night mode) – falls back to defaults
  loadSettings();
```

- [ ] **Step 4: Compile-verify**

Run: `arduino-cli compile --fqbn esp8266:esp8266:nodemcu rgbw_stair_light`
Expected: compiles clean, no errors. (Globals are unused so far — that is fine; Task 2 wires them in.)

- [ ] **Step 5: Commit**

```bash
git add rgbw_stair_light/rgbw_stair_light.ino
git commit -m "Add EEPROM-backed Settings struct (hostname, night mode)"
```

---

## Task 2: Use persisted settings for night mode + hostname

**Files:**
- Modify: `rgbw_stair_light/rgbw_stair_light.ino` (`isNightMode()`, and `setup()` hostname usage)

- [ ] **Step 1: Make `isNightMode()` read the settings**

Replace the body of `isNightMode()` (currently around line 611) with:

```cpp
bool isNightMode(long unixTimeUtc) {
  if (!g_settings.nightEnabled) return false;
  if (unixTimeUtc <= 0) return false;
  time_t t = (time_t)(unixTimeUtc + TIMEZONE_OFFSET_SEC(unixTimeUtc));
  struct tm *tm = gmtime(&t);
  if (!tm) return false;
  int hour = tm->tm_hour;
  return (hour >= g_settings.nightStart && hour < g_settings.nightEnd);
}
```

- [ ] **Step 2: Set the WiFi (DHCP) hostname before connecting**

In `setup()`, immediately **before** `WiFi.begin(WIFI_SSID, WIFI_PASS);`:

```cpp
  // Register our name on the network (DHCP) using the persisted hostname
  WiFi.hostname(g_settings.hostname);
  WiFi.begin(WIFI_SSID, WIFI_PASS);
```

- [ ] **Step 3: Use the persisted hostname for OTA**

Replace `ArduinoOTA.setHostname(OTA_HOSTNAME);` (around line 701) with:

```cpp
    ArduinoOTA.setHostname(g_settings.hostname);
```

- [ ] **Step 4: Compile-verify**

Run: `arduino-cli compile --fqbn esp8266:esp8266:nodemcu rgbw_stair_light`
Expected: compiles clean.

- [ ] **Step 5: Commit**

```bash
git add rgbw_stair_light/rgbw_stair_light.ino
git commit -m "Drive night mode and hostname from persisted settings"
```

---
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

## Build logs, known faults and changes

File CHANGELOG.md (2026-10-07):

# Changelog

## 2.8.1 – 2026-10-08

- **Matrix runs 60 s from the web UI** (`MATRIX_WEB_MS`); the other animations still run 10 s there, and motion-triggered Matrix still runs 20 s.
- **Matrix tile looks like the film** – The web UI preview now shows falling columns of green katakana and digits with bright leading characters that keep changing, instead of plain green stripes.
- **Shorter, softer startup signal** – After a restart the stairs show three soft pulses (green with a little white) that fade in and out, 2 s in total and very dim, instead of three hard 1 s green blinks at 50 % (6 s).

## 2.8.0 – 2026-10-05

- **Rainbow reworked** – The rainbow now fades in as a smooth wave in walking direction: each step brightens over ~1 s and the next one starts when the previous is at 20 % (200 ms later; `RAINBOW_FADE_MS`, `RAINBOW_STAGGER_MS`), so the whole staircase is lit after ~4 s. The colours already flow while the steps fade in and out, and fade-in, animation and fade-out are drawn by the same code, so there is no visible colour or brightness jump between them. It runs for the full `ANIM_DURATION` (20 s, including the fade-in) like the other animations – previously it stopped after two colour cycles (~5 s down / ~10 s up). Up and down flow at the same speed (`RAINBOW_CYCLE_MS`, one colour cycle per 5 s), colours travelling in walking direction; fade-out is a quicker wave (~1.5 s). External control still interrupts it (it fades out from wherever it is).
- **Smoother fades via dithering** – Brightness and hue are computed at 256x finer resolution, and in-between levels are shown by alternating between neighbouring levels from frame to frame (all LEDs of a step stay identical). Fades no longer start in visible jumps at the dark end. `RAINBOW_DITHER 0` turns it off for comparison.
- **Star sparkle: real twinkling stars** – Stars used to flash for a single frame (~17 ms) at full brightness. Now each star switches on at a random brightness (`STAR_MIN_PEAK` 25 %–100 %) and fades out calmly over 0.75–1.5 s (`STAR_FADE_MS`), with ~20 new stars per second (`STAR_RATE`). The blue backdrop fades in and out as a wave like the night animation (1.5 s per step, next step starting at 10 %, ~3.7 s in total; `WAVE_FADE_MS`, `WAVE_STAGGER_MS`), and stars dim along with their step during the fades.
- **Birthday: calm confetti** – Instead of giving all 432 LEDs a new random colour every frame (and switching on/off instantly), about three quarters of the LEDs (`BDAY_ON_PCT` 75 %) now glow in random colours at random brightness, each fading in and out over 2–4 s (`BDAY_LIFE_MS`); when one goes dark another random LED takes over. It fades in and out as the same wave as the star sparkle (`WAVE_FADE_MS`, `WAVE_STAGGER_MS`).
- **New animation: Matrix** – "The Matrix" digital rain: each of the 27 LED positions is a column, and green drops with a white-green head and fading trail fall down the stairs at different speeds (`MATRIX_DROP_SPEED`, `MATRIX_TRAIL`), with trail LEDs flickering now and then. A faint green glow (`MATRIX_BASE`, 0 = black) keeps the steps visible. It fades in and out as the same wave as the star sparkle, joins the random motion rotation and has its own tile in the web UI (`/api/play anim=7`).
- **Random colour animation removed** – Motion now picks from Rainbow, White ramp, Star sparkle and Matrix (no back-to-back repeat). `/api/play` accepts `anim=2..7`.
- **New web UI** – Redesigned page: animation tiles with live previews (the tile of the animation that is playing, from the web or from motion, shows a progress ring), fixed colour with RGBW sliders and presets, recent motion as a timeline, device status with memory, flash and WiFi at a glance plus a full detail table, and settings, birthdays and restart (with an in-page confirmation). Form fields are 16 px so iOS does not zoom in. The page lives in `web_ui.h`; fonts load from Google Fonts when online, otherwise system fonts are used.
- **`/api/state` reports the running animation** – New fields `anim` (0 = none, 2–7), and while one runs `anim_ms`, `anim_len` and `dir`. All animations now start through one `runAnimation()` function.
- **Fix: night-mode motions showed no animation name** in the motion log (`/api/log` now returns "Night red").
- **Fix: red and green were swapped in the colour helpers** – `red()`/`green()` in `parking.h` read the wrong byte, which made the old rainbow fade in with red and green exchanged and then jump to the correct colours.
- **Automation switch survives restarts** – Turning stair automation off (web UI or `/api/auto`) is now saved, so the device comes back the same way after a restart or power cut. Existing devices start with automation on, as before. This makes the firmware identical for every device (only `credentials.h` differs), so one build can be uploaded to several devices.

## 2.7.0 – 2026-06-08

- **External control now preempts a running animation** – A `POST /api/ext` command (red/red_blink/yellow_blink/green_fade/clean/clear) now interrupts an in-progress motion animation instead of waiting for it (and its 10 s post-delay) to finish. The animation hold-phases and the post-animation delay abort as soon as a command is pending, so the strip switches to the requested state within ~1–2 s instead of up to ~30 s.

## 2.6.1 – 2026-06-08

- **Docs** – Added a German Siri/Kurzbefehle setup guide to the README. Documentation only; no firmware behaviour change vs 2.6.0.

## 2.6.0 – 2026-06-07

- **Cleaning light fades in/out** – `state=clean` now ramps up smoothly from 0 to 250 over ~500 ms instead of switching on instantly, and fades back down 250→0 over ~500 ms when it ends (on `clear`/"Staubsaugen aus" and on the 10-minute auto-timeout).

## 2.5.2 – 2026-06-07

- **Fix: no spurious animation after an external override ends** – After `clear` (e.g. "Staubsaugen aus"), a green_fade finishing, or a hold timeout, the firmware now ignores the PIR sensors until they next read idle. Previously the lingering presence from the cleaning session (PIR still HIGH) immediately triggered an animation. A genuinely new motion still triggers normally.

## 2.5.1 – 2026-06-07

- **Cleaning light brightness** – `state=clean` now drives all channels to **250** (instead of 255) to leave a little headroom on power/drivers.

## 2.5.0 – 2026-06-07

- **Cleaning light ("Staubsaugen")** – `POST /api/ext state=clean` turns every LED to full brightness (all channels 255) for vacuuming/cleaning, held for up to **10 minutes** or until `state=clear` ("Staubsaugen aus"). Re-sending `clean` resets the 10-minute timer. Intended to be triggered by an Apple Shortcut via Siri ("Hey Siri, Staubsaugen!"). Note: all-channels-255 across 432 LEDs is a heavy sustained current draw — ensure the PSU/wiring can handle it.

## 2.4.0 – 2026-06-07

- **External control safety timeout** – Held states (`red`, `red_blink`, `yellow_blink`) now auto-release after **5 minutes** if no new `/api/ext` command arrives, returning to normal operation (motion automation / night mode). Each command resets the timer. `green_fade` already self-terminates (~30 s) and is unaffected. This prevents the stairs getting stuck if the controlling process crashes or loses WiFi.

## 2.3.0 – 2026-06-07

- **External control: blinking yellow** – `POST /api/ext` now accepts `state=yellow_blink`, which blinks the strip yellow (red + green) every 500 ms until the next command. Like the other external states, it suppresses motion detection while active.

## 2.2.1 – 2026-06-07

- **Night mode across midnight** – Fix: a night window where the start hour is later than the end hour (e.g. 23–6) now works. Previously only same-day windows (start < end) activated.
- **Birthday table labels** – The Birthdays editor now shows Month / Day / Name column headers and `MM`/`DD` placeholders so it's clear which field is which.

## 2.2.0 – 2026-06-07

- **Web-editable birthdays** – View and edit the birthday list (month, day, optional name) in the web UI under "Birthdays"; add/remove rows and Save. Each birthday can have a short name shown in the UI.
- **Persistent birthdays** – Birthdays are stored in a dedicated EEPROM region (separate from settings) and survive reboot; `birthdays.h` is now only the first-boot default. Up to 20 entries.
- **New endpoints** – `GET`/`POST /api/birthdays`.

## 2.1.0 – 2026-06-06

- **External control API** – `POST /api/ext` with `state=red|red_blink|green_fade|clear` lets another LAN process drive the strip directly (solid red, 500 ms red blink, ~30 s green dim-down). Motion detection is suppressed while active; normal behaviour (or night mode) resumes after `green_fade`/`clear`.
- **Web-configurable settings** – Hostname and night mode (enable toggle + start/end hours) are now editable in the web UI under "Settings".
- **Persistent settings** – Hostname and night-mode settings are stored in EEPROM and survive reboot (fall back to compiled defaults on first boot). Hostname changes apply after reboot.
- **New endpoints** – `GET`/`POST /api/settings`.

## 1.0.0 – 2026-04-04

- **Night mode indicator** – Web UI shows a red badge when night mode is active (hours displayed).
- **Firmware version** – Version number (`FW_VERSION`) shown at the bottom of the web UI.
- **Night mode API** – `/api/state` now includes a `night` field (1 = active, 0 = inactive).
- Updated night mode defaults: 1:00–6:00, brightness max 50, min 10.

## Pre-1.0 (October 2016 – March 2026)

Initial development: animated stair lighting with SK6812 RGBW LEDs, PIR motion detection, OTA updates, web UI with manual colour control, stair automation toggle, animation test, night mode (red breathing), birthday animation, NTP time, reboot button, motion log, memory/CPU/WiFi status tables, All presets, firewall workaround scripts.

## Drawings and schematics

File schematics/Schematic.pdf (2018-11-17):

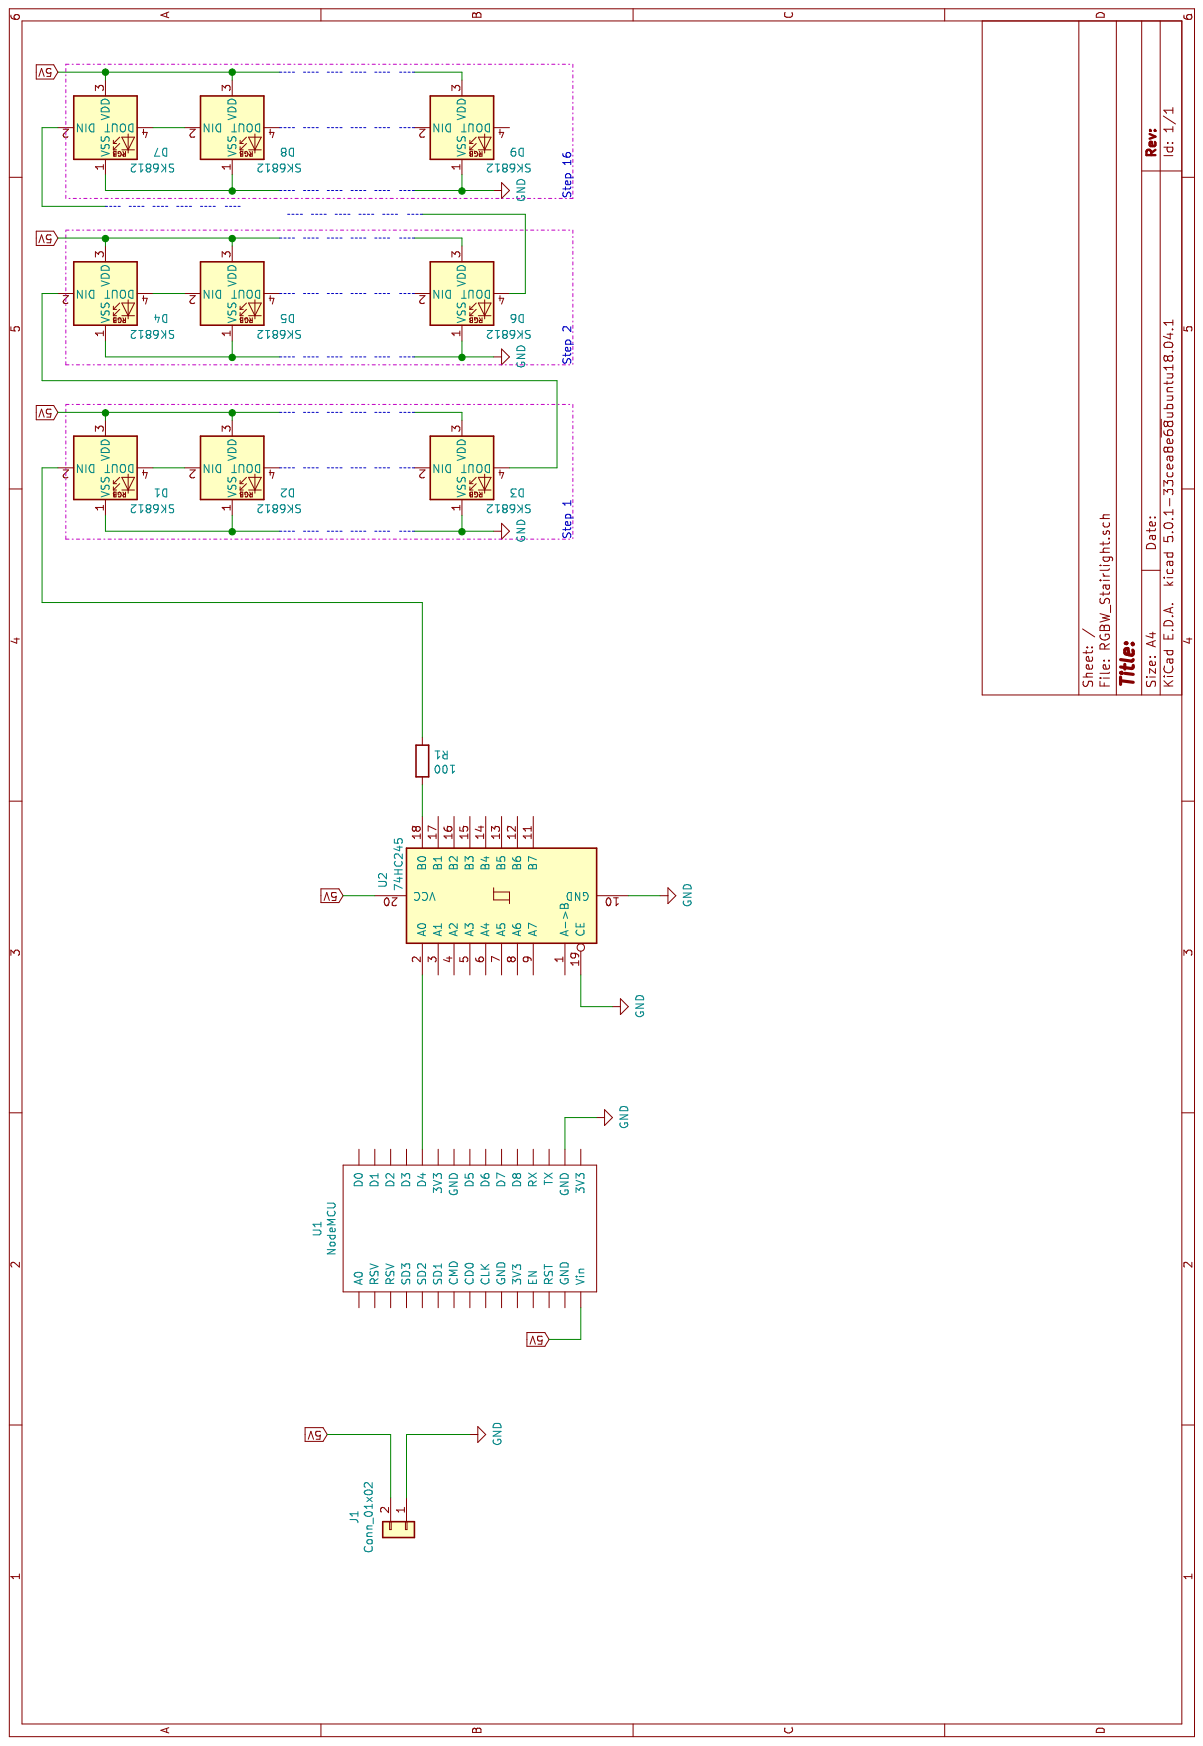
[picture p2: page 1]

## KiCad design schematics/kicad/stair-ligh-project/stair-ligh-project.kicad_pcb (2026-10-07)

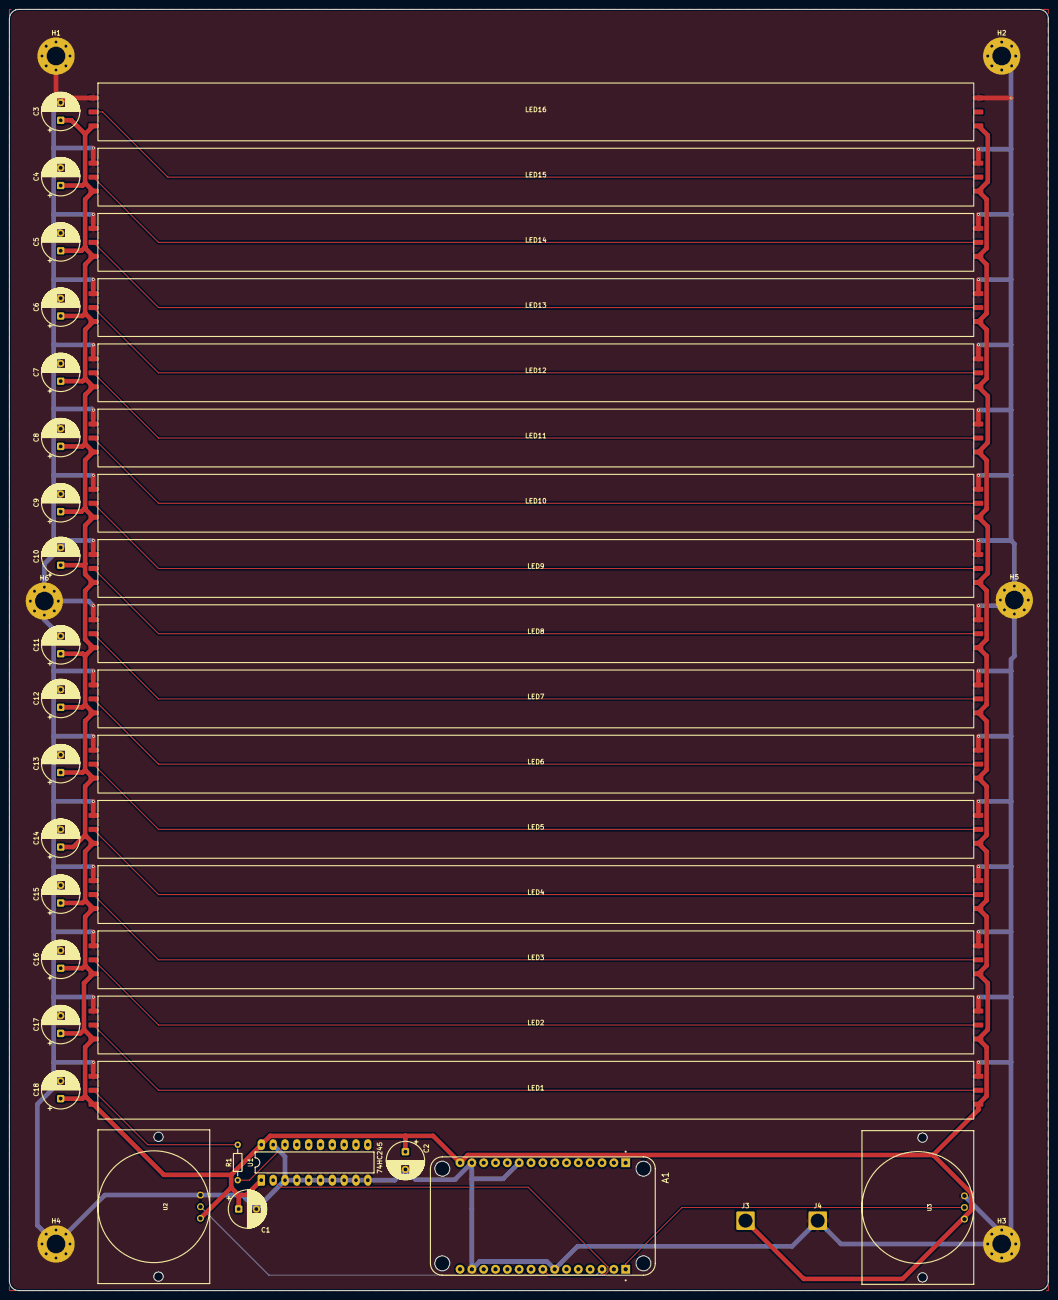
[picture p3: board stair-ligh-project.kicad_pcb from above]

Board: 2 copper layers, 223.0 x 275.0 mm, 47 parts (0 on the bottom side), 22 nets.

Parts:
A1: 113990105; NodeMCU_v2
C1, C2: 0.1; CP_Radial_D8.0mm_P3.80mm
C3, C4, C5, C6, C7, C8, C9, C10, C11, C12, C13, C14, C15, C16, C17, C18: CP; CP_Radial_D8.0mm_P3.80mm
H1, H2, H3, H4, H5, H6: MountingHole_Pad; MountingHole_4mm_Pad_Via
J3, J4: Conn_01x01; SolderWire-2.5sqmm_1x01_D2.4mm_OD3.6mm
LED1, LED2, LED3, LED4, LED5, LED6, LED7, LED8, LED9, LED10, LED11, LED12, LED13, LED14, LED15, LED16: LED_Row
R1: 470; R_Axial_DIN0204_L3.6mm_D1.6mm_P7.62mm_Horizontal
U1: 74HC245; DIP-20_W7.62mm_LongPads
U2, U3: HC-SR501

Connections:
+5V: A1.J1_15 (VIN), C1.1, C2.1, C3.1, C4.1, C5.1, C6.1, C7.1, C8.1, C9.1, C10.1, C11.1, C12.1, C13.1, C14.1, C15.1, C16.1, C17.1, C18.1, J3.1 (Pin_1_1), LED1.3 (5V), LED1.4 (+5V), LED2.3 (5V), LED2.4 (+5V), LED3.3 (5V), LED3.4 (+5V), LED4.3 (5V), LED4.4 (+5V), LED5.3 (5V), LED5.4 (+5V), LED6.3 (5V), LED6.4 (+5V), LED7.3 (5V), LED7.4 (+5V), LED8.3 (5V), LED8.4 (+5V), LED9.3 (5V), LED9.4 (+5V), LED10.3 (5V), LED10.4 (+5V), LED11.3 (5V), LED11.4 (+5V), LED12.3 (5V), LED12.4 (+5V), LED13.3 (5V), LED13.4 (+5V), LED14.3 (5V), LED14.4 (+5V), LED15.3 (5V), LED15.4 (+5V), LED16.3 (5V), LED16.4 (+5V), U1.1 (A->B), U1.20 (VCC), U2.1 (GND), U3.1 (GND)
GND: A1.J1_10 (GND), A1.J1_14 (GND), A1.J2_7 (GND), A1.J2_14 (GND), C1.2, C2.2, C3.2, C4.2, C5.2, C6.2, C7.2, C8.2, C9.2, C10.2, C11.2, C12.2, C13.2, C14.2, C15.2, C16.2, C17.2, C18.2, H1.1 (1_1), H2.1 (1_1), H3.1 (1_1), H4.1 (1_1), H5.1 (1_1), H6.1 (1_1), J4.1 (Pin_1_1), LED1.1 (GND), LED1.6 (GND), LED2.1 (GND), LED2.6 (GND), LED3.1 (GND), LED3.6 (GND), LED4.1 (GND), LED4.6 (GND), LED5.1 (GND), LED5.6 (GND), LED6.1 (GND), LED6.6 (GND), LED7.1 (GND), LED7.6 (GND), LED8.1 (GND), LED8.6 (GND), LED9.1 (GND), LED9.6 (GND), LED10.1 (GND), LED10.6 (GND), LED11.1 (GND), LED11.6 (GND), LED12.1 (GND), LED12.6 (GND), LED13.1 (GND), LED13.6 (GND), LED14.1 (GND), LED14.6 (GND), LED15.1 (GND), LED15.6 (GND), LED16.1 (GND), LED16.6 (GND), U1.3 (A1), U1.4 (A2), U1.5 (A3), U1.6 (A4), U1.7 (A5), U1.8 (A6), U1.9 (A7), U1.10 (GND), U1.19 (CE), U2.3 (5V), U3.3 (5V)
Level Shifter: A1.J2_8 (D5), U1.2 (A0)
Neopixel: LED1.2 (Din), R1.2
unnamed: LED1.5 (Dout), LED2.2 (Din)
unnamed: LED2.5 (Dout), LED3.2 (Din)
unnamed: LED3.5 (Dout), LED4.2 (Din)
unnamed: LED4.5 (Dout), LED5.2 (Din)
unnamed: LED5.5 (Dout), LED6.2 (Din)
unnamed: LED6.5 (Dout), LED7.2 (Din)
unnamed: LED7.5 (Dout), LED8.2 (Din)
unnamed: LED8.5 (Dout), LED9.2 (Din)
unnamed: LED9.5 (Dout), LED10.2 (Din)
unnamed: LED10.5 (Dout), LED11.2 (Din)
unnamed: LED11.5 (Dout), LED12.2 (Din)
unnamed: LED12.5 (Dout), LED13.2 (Din)
unnamed: LED13.5 (Dout), LED14.2 (Din)
unnamed: LED14.5 (Dout), LED15.2 (Din)
unnamed: LED15.5 (Dout), LED16.2 (Din)
unnamed: R1.1, U1.18 (B0)
PIR1: A1.J2_1 (D0), U3.2 (OUT)
PIR2: A1.J2_3 (D2), U2.2 (OUT)

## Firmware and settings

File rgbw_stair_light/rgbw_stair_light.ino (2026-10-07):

// STAIR LIGHT PROJECT - started October 2016
// ==========================================
//
// This project is using NeoPixels to illuminate individual steps of a flight of stairs
// automatically, while someone is walking up (or down) the stairs. The project is based  
// on an ESP8266 as microcontroller, strips of SK2812 as LEDs (should be compatible to
// WS2812) and two SR501 as motion sensors. An ESP8266 is used as the microcontroller.
// I have tried to make it easy to adapt this sketch to your own needs.
// You can e.g. change the number of steps of your stairs (STEPS) as well as
// the 'width' of your stairs, in terms of how many LEDs are you using per step (WIDTH).
// I have written a few animations, much of this code is based on the strandtest code
// example from adafruit, with some adaptations however.
//
// This is pretty much work in progress.
//
// There is some tweaking needed depending on local parameters with the PIR sensors,
// the ANIM_DURATION and the delay after each animation. For me it worked when I set
// the activation time potentiometer to minimum (which results to about 4 seconds of
// the pin set to high), an ANIM_DURATION of 20 seconds (because in my house, one needs
// about 10 seconds to go up the stairs at normal speed) and a delay after each
// animation of 7 seconds. You will have to play around to fit your needs.
//
//
// last update 30.03.2018
//

#include <Arduino.h>
#include <Adafruit_NeoPixel.h>
#include <time.h>
#include <ESP8266WiFi.h>
#include <WiFiClient.h>
#include <ESP8266WiFiMulti.h>
#include <ESP8266mDNS.h>
#include <ESPAsyncTCP.h>
#include <ESPAsyncWebServer.h>
#include <ArduinoOTA.h>
#include <EasyNTPClient.h>
#include <WiFiUdp.h>
#include "credentials.h"
#include "birthdays.h"
#include <Ticker.h>
#include <EEPROM.h>
#include <time.h>

#ifdef __AVR__
  #include <avr/power.h>
#endif

// Pin Assignment: it turns out that GPIO 15 and 2 influence the boot mode
// of the ESP8266, so they should not be used ever.
//

#define NEOPIXEL_PIN  14          // Pin D5 == GPIO 14 -> NeoPixels
#define PIR1 16                   // Pin D0 == GPIO 16 -> PIR Sensor 1
#define PIR2 4                    // Pin D2 == GPIO 4  -> Pir Sensor 2
#define STEPS 16                  // how many steps do the stairs have?
#define WIDTH 27                  // how many LEDs per step do we have?
#define NUM_LEDS (STEPS * WIDTH)  // how many LEDs do we have overall?
#define ANIM_DURATION 20000       // Duration of each animation (ms), then fade-out
#define POST_ANIM_DELAY_MS 10000  // Delay after animation before next motion trigger (ms)
#define RAINBOW_CYCLE_MS 5000     // Rainbow: time for one full trip through all colours (ms)
#define RAINBOW_FADE_MS 1000      // Rainbow: fade-in time of one step (ms)
#define RAINBOW_STAGGER_MS 200    // Rainbow: next step starts fading in this much later (ms; 200 = when the previous is at 20%)
#define RAINBOW_DITHER 1          // Rainbow: 1 = in-between brightness by alternating levels over frames, 0 = off
#define STAR_RATE 20              // Star sparkle: new stars per second
#define STAR_FADE_MS 1500         // Star sparkle: longest star fade-out (ms); each star takes 50-100% of it
#define STAR_MIN_PEAK 25          // Star sparkle: start brightness of the faintest star (%; brightest = 100)
#define WAVE_FADE_MS 1500         // Star sparkle + birthday: fade-in/out time of one step (ms)
#define WAVE_STAGGER_MS 150       // Star sparkle + birthday: next step starts this much later (150 = at 10%, like night red)
#define BDAY_ON_PCT 75            // Birthday: share of LEDs glowing at any moment (%; 75 = a quarter dark)
#define BDAY_LIFE_MS 4000         // Birthday: longest glow of one LED (ms); each takes 50-100% of it
#define MATRIX_DROP_SPEED 8       // Matrix: average fall speed (steps per second; each drop 0.5-1.25x)
#define MATRIX_TRAIL 9            // Matrix: longest trail behind a drop (steps; shortest is half)
#define MATRIX_BASE 6             // Matrix: faint green glow on every step (0-255 PWM; 0 = pure black)
#define MATRIX_WEB_MS 60000       // Matrix started from the web UI runs this long (others: 10 s)
// Auto-detect CET/CEST: UTC+1 in winter, UTC+2 in summer (last Sun of March – last Sun of October)
static long timezoneOffsetSec(long utc) {
  time_t t = (time_t)utc;
  struct tm *g = gmtime(&t);
  int month = g->tm_mon + 1;   // 1-12
  int day   = g->tm_mday;
  int wday  = g->tm_wday;      // 0=Sun
  int hour  = g->tm_hour;
  // Last Sunday of month = last day minus (wday of last day)
  // For March/October: switch happens at 01:00 UTC on last Sunday
  if (month < 3 || month > 10) return 3600;        // Nov–Feb: CET (UTC+1)
  if (month > 3 && month < 10) return 7200;         // Apr–Sep: CEST (UTC+2)
  // March: CEST starts last Sunday at 01:00 UTC
  int lastSun = 31 - ((5 + wday + 31 - day) % 7);  // last Sunday's date this month
  if (month == 3) {
    if (day < lastSun) return 3600;
    if (day > lastSun) return 7200;
    return (hour < 1) ? 3600 : 7200;
  }
  // October: CET starts last Sunday at 01:00 UTC
  lastSun = 31 - ((2 + wday + 31 - day) % 7);
  if (day < lastSun) return 7200;
  if (day > lastSun) return 3600;
  return (hour < 1) ? 7200 : 3600;
}
#define TIMEZONE_OFFSET_SEC timezoneOffsetSec
// if BRIGHNESS is too small (around 10 or less), the animation appears 'skippy', i.e. not smooth
// that is because there are only a few (10) levels of brighness for each color, so this is normal
#define BRIGHTNESS 255            // limit brightness of the strip
#define USE_SERIAL Serial
#define DEBUG 1   // 1 = Serial monitor shows PIR state and trigger

ESP8266WiFiMulti WiFiMulti;
AsyncWebServer server(80);

// Web control: stair automation and manual colour (0–100% per channel)
bool automationOn = true;   // restored from g_settings.automationOff at boot, toggled via web
uint8_t manual_r = 0, manual_g = 0, manual_b = 0, manual_w = 0;  // 0–100 %

// If > 0: animations (e.g. web "Go") run only for this duration (ms), else ANIM_DURATION
uint32_t g_animDurationOverrideMs = 0;

// Flags set by async web handlers, consumed by loop()
volatile int g_pendingPlayAnim = 0;   // 0 = none, 2-7 = animation to play

// What the strip is playing right now, for the web UI's live view (/api/state)
volatile uint8_t       g_curAnim = 0;        // 0 = none, 2-7 as above
volatile unsigned long g_curAnimStart = 0;   // millis() when it started
volatile uint32_t      g_curAnimLen = 0;     // its duration before the fade-out (ms)
volatile bool          g_curAnimDown = false;
volatile bool g_pendingReboot = false;

// External control (parking/garage signalling). Web handler sets g_pendingExtCmd;
// loop() applies it and drives the strip non-blocking while g_extActive is true.
enum ExtMode { EXT_NONE = 0, EXT_RED, EXT_RED_BLINK, EXT_GREEN_FADE, EXT_YELLOW_BLINK, EXT_CLEAN };
volatile int  g_pendingExtCmd = 0;   // 0=none,1=red,2=red_blink,3=green_fade,4=clear,5=yellow_blink,6=clean
ExtMode       g_extMode    = EXT_NONE;
bool          g_extActive  = false;
unsigned long g_extStartMs = 0;      // green_fade start time
unsigned long g_extBlinkMs = 0;      // red_blink last toggle time
bool          g_extBlinkOn = false;
unsigned long g_extLastCmdMs = 0;    // time of last /api/ext command (for hold timeout)
#define EXT_HOLD_TIMEOUT_MS 300000uL // held states (red/red_blink/yellow_blink) auto-clear after 5 min
#define EXT_CLEAN_TIMEOUT_MS 600000uL // clean (full brightness) auto-clears after 10 min

// Last NTP time (UTC) from main loop; used by /api/time for Web UI date/time display
volatile long g_lastNtpTime = 0;
// First valid NTP time after boot (for "last reboot" display in Web UI)
static long s_bootTimeUtc = 0;

// Reset reason / exception info cached once at boot (before WiFi changes them)
static String s_resetReason;
static String s_resetInfo;

// WiFi reconnect counter (incremented on every re-connect after the first one)
static uint32_t g_wifiReconnectCount = 0;
static WiFiEventHandler g_wifiReconnectHandler;

// Last 5 motion events (direction + animation) for Web UI log
#define MOTION_LOG_SIZE 5
struct MotionLogEntry { char dir[6]; uint8_t anim_id; long timestamp; };
MotionLogEntry motionLog[MOTION_LOG_SIZE];
uint8_t motionLogHead = 0;
uint8_t motionLogCount = 0;

void addMotionLog(const char* dir, uint8_t anim_id) {
  strncpy(motionLog[motionLogHead].dir, dir, 5);
  motionLog[motionLogHead].dir[5] = '\0';
  motionLog[motionLogHead].anim_id = anim_id;
  motionLog[motionLogHead].timestamp = g_lastNtpTime;
  motionLogHead = (motionLogHead + 1) % MOTION_LOG_SIZE;
  if (motionLogCount < MOTION_LOG_SIZE) motionLogCount++;
}

Adafruit_NeoPixel strip = Adafruit_NeoPixel(NUM_LEDS, NEOPIXEL_PIN, NEO_GRBW + NEO_KHZ800);



int gammaw[] = {
    0,  0,  0,  0,  0,  0,  0,  0,  0,  0,  0,  0,  0,  0,  0,  0,
    0,  0,  0,  0,  0,  0,  0,  0,  0,  0,  0,  0,  1,  1,  1,  1,
    1,  1,  1,  1,  1,  1,  1,  1,  1,  2,  2,  2,  2,  2,  2,  2,
    2,  3,  3,  3,  3,  3,  3,  3,  4,  4,  4,  4,  4,  5,  5,  5,
    5,  6,  6,  6,  6,  7,  7,  7,  7,  8,  8,  8,  9,  9,  9, 10,
   10, 10, 11, 11, 11, 12, 12, 13, 13, 13, 14, 14, 15, 15, 16, 16,
   17, 17, 18, 18, 19, 19, 20, 20, 21, 21, 22, 22, 23, 24, 24, 25,
   25, 26, 27, 27, 28, 29, 29, 30, 31, 32, 32, 33, 34, 35, 35, 36,
   37, 38, 39, 39, 40, 41, 42, 43, 44, 45, 46, 47, 48, 49, 50, 50,
   51, 52, 54, 55, 56, 57, 58, 59, 60, 61, 62, 63, 64, 66, 67, 68,
   69, 70, 72, 73, 74, 75, 77, 78, 79, 81, 82, 83, 85, 86, 87, 89,
   90, 92, 93, 95, 96, 98, 99,101,102,104,105,107,109,110,112,114,
  115,117,119,120,122,124,126,127,129,131,133,135,137,138,140,142,
  144,146,148,150,152,154,156,158,160,162,164,167,169,171,173,175,
  177,180,182,184,186,189,191,193,196,198,200,203,205,208,210,213,
  215,218,220,223,225,228,231,233,236,239,241,244,247,249,252,255 };

// Firmware version – shown in web UI footer
#define FW_VERSION "2.8.1"

// Night mode parameters – defined here so parking.h can use them
#define NIGHT_HOUR_START      1   // 1:00
#define NIGHT_HOUR_END        6   // 6:00 (exclusive)
#define NIGHT_BRIGHTNESS_MAX  50  // max red value during night (≈ 20%)
#define NIGHT_BRIGHTNESS_MIN  10  // min red value (never fully off)

#include "parking.h"

// ---- Persistent settings (EEPROM emulation) -------------------------------
// A small versioned struct. On first boot / blank flash / version change we
// fall back to the compiled-in defaults and re-save. The struct fields are the
// runtime config (read directly elsewhere) – no separate shadow globals.
// EEPROM is shared: Settings at offset 0, birthdays at a fixed offset further in.
#define EEPROM_SIZE            1024
#define EEPROM_BIRTHDAYS_ADDR  128   // Settings live at offset 0; leave headroom to grow
#define SETTINGS_MAGIC   0x53544C31u  // 'STL1'
#define SETTINGS_VERSION 1
struct Settings {
  uint32_t magic;
  uint8_t  version;
  char     hostname[32];   // null-terminated, <=31 chars
  bool     nightEnabled;
  uint8_t  nightStart;     // hour 0–23 (inclusive)
  uint8_t  nightEnd;       // hour 0–23 (exclusive)
  uint8_t  automationOff;  // 1 = automation off (survives restarts); anything else = on.
                           // Added without a version bump: older devices read their unused
                           // EEPROM byte here (0 or 0xFF), so they keep automation on.
};
static_assert(sizeof(Settings) <= EEPROM_BIRTHDAYS_ADDR, "settings would overlap birthdays");
Settings g_settings;

void saveSettings() {
  EEPROM.begin(EEPROM_SIZE);   // begin re-reads flash into RAM; keep begin→put→commit as a unit
  EEPROM.put(0, g_settings);
  EEPROM.commit();
}

void loadSettings() {
  EEPROM.begin(EEPROM_SIZE);
  EEPROM.get(0, g_settings);
  if (g_settings.magic != SETTINGS_MAGIC || g_settings.version != SETTINGS_VERSION) {
    // First boot / blank / version mismatch → compiled defaults
    g_settings.magic   = SETTINGS_MAGIC;
    g_settings.version = SETTINGS_VERSION;
    strncpy(g_settings.hostname, OTA_HOSTNAME, sizeof(g_settings.hostname) - 1);
    g_settings.hostname[sizeof(g_settings.hostname) - 1] = '\0';
    g_settings.nightEnabled = true;
    g_settings.nightStart   = NIGHT_HOUR_START;
    g_settings.nightEnd     = NIGHT_HOUR_END;
    g_settings.automationOff = 0;
    saveSettings();
  }
}

// ---- Persistent birthdays (separate EEPROM region) ------------------------
// Independent magic/version so it self-heals without touching the Settings
// region. Seeded from the compile-time birthdays.h list on first boot.
#define BIRTHDAYS_MAX     20
#define BIRTHDAY_NAME_LEN 20            // includes null terminator (<=19 visible chars)
#define BIRTHDAYS_MAGIC   0x53544231u   // 'STB1'
#define BIRTHDAYS_VERSION 1
struct BirthdayStore {
  uint32_t magic;
  uint8_t  version;
  uint8_t  count;                       // 0..BIRTHDAYS_MAX
  struct {
    uint8_t month;                      // 1..12
    uint8_t day;                        // 1..31
    char    name[BIRTHDAY_NAME_LEN];    // null-terminated, may be empty
  } items[BIRTHDAYS_MAX];
};
BirthdayStore g_birthdays;

void saveBirthdays() {
  EEPROM.begin(EEPROM_SIZE);
  EEPROM.put(EEPROM_BIRTHDAYS_ADDR, g_birthdays);
  EEPROM.commit();
}

void loadBirthdays() {
  EEPROM.begin(EEPROM_SIZE);
  EEPROM.get(EEPROM_BIRTHDAYS_ADDR, g_birthdays);
  if (g_birthdays.magic != BIRTHDAYS_MAGIC || g_birthdays.version != BIRTHDAYS_VERSION) {
    // First boot / blank / schema change → seed from compiled birthdays.h defaults
    g_birthdays.magic   = BIRTHDAYS_MAGIC;
    g_birthdays.version = BIRTHDAYS_VERSION;
    uint8_t n = (BIRTHDAY_COUNT > BIRTHDAYS_MAX) ? BIRTHDAYS_MAX : (uint8_t)BIRTHDAY_COUNT;
    g_birthdays.count = n;
    for (uint8_t i = 0; i < n; i++) {
      g_birthdays.items[i].month   = BIRTHDAYS[i][0];
      g_birthdays.items[i].day     = BIRTHDAYS[i][1];
      g_birthdays.items[i].name[0] = '\0';
    }
    saveBirthdays();
  }
}

WiFiUDP udp;
EasyNTPClient ntpClient(udp, "pool.ntp.org", ((0*60*60)+(0*60))); // CET = GMT + 1:00

Ticker secondTick;
volatile int watchdogCount = 0;

void ISRwatchdog() {
  watchdogCount++;
  if (watchdogCount == 360) {
    Serial.println();
    Serial.println("the watchdog bites!!!");
    ESP.restart();
  }

}

// Apply manual colour (R,G,B,W 0–100%) to strip (with gamma).
// 1–100% mapped to gamma index 25–255 so 10% is already visible.
static uint8_t manualPctToGamma(uint8_t pct) {
  if (pct == 0) return 0;
  int idx = 25 + (int)((unsigned long)pct * 230 / 100);
  if (idx > 255) idx = 255;
  return gammaw[idx];
}
void applyManualColor() {
  uint8_t r = manualPctToGamma(manual_r);
  uint8_t g = manualPctToGamma(manual_g);
  uint8_t b = manualPctToGamma(manual_b);
  uint8_t w = manualPctToGamma(manual_w);
  setAll(r, g, b, w);
  strip.show();
}

// Statisches Frontend (cachebar), State und Aktionen per API
#include "web_ui.h"

void handleIndex(AsyncWebServerRequest *request) {
  AsyncWebServerResponse *response = request->beginResponse_P(200, F("text/html"), INDEX_HTML);
  response->addHeader(F("Cache-Control"), F("public, max-age=3600"));
  request->send(response);
}

void handleApiState(AsyncWebServerRequest *request) {
  String json = "{\"auto\":";
  json += automationOn ? "1" : "0";
  json += ",\"r\":"; json += manual_r;
  json += ",\"g\":"; json += manual_g;
  json += ",\"b\":"; json += manual_b;
  json += ",\"w\":"; json += manual_w;
  json += ",\"night\":"; json += isNightMode(g_lastNtpTime) ? "1" : "0";
  uint8_t anim = g_curAnim;
  json += ",\"anim\":"; json += anim;
  if (anim) {
    json += ",\"anim_ms\":"; json += (unsigned long)(millis() - g_curAnimStart);
    json += ",\"anim_len\":"; json += (unsigned long)g_curAnimLen;
    json += ",\"dir\":\""; json += g_curAnimDown ? "DOWN" : "UP"; json += "\"";
  }
  json += "}";
  AsyncWebServerResponse *response = request->beginResponse(200, F("application/json"), json);
  response->addHeader(F("Cache-Control"), F("no-store"));
  request->send(response);
}

void handleApiAuto(AsyncWebServerRequest *request) {
  if (request->hasParam(F("on"), true)) {
    automationOn = (request->getParam(F("on"), true)->value().toInt() != 0);
    uint8_t off = automationOn ? 0 : 1;
    if (g_settings.automationOff != off) { g_settings.automationOff = off; saveSettings(); }
    if (!automationOn) applyManualColor();
    else { setAll(0, 0, 0, 0); strip.show(); }
  }
  request->send(204);
}
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
void loop() {
  Serial.println("");
  int count = 0;
  String dir = "";
  int currenttime = 0;
  int lastPir1 = -1, lastPir2 = -1;  // for debug: detect change
  static int lastAnimation = 0;      // 0 = none yet, else the last chosen animation (no repeat)
  static bool wasNightMode = false;
  bool extWasActive = false;         // tracks external-override active state across iterations
  bool ignoreMotionUntilLow = false; // after an override ends, ignore lingering PIR HIGH
  while (true) {
    ArduinoOTA.handle();
    watchdogCount = 0;

    // Handle pending reboot from web UI
    if (g_pendingReboot) {
      delay(300);
      ESP.restart();
    }

    // Handle pending animation from web UI
    if (g_pendingPlayAnim > 0) {
      int anim = g_pendingPlayAnim;
      g_pendingPlayAnim = 0;
      g_animDurationOverrideMs = (anim == 7) ? MATRIX_WEB_MS : 10000;
      runAnimation(anim, F("UP"));
      g_animDurationOverrideMs = 0;
      if (!automationOn) applyManualColor();
      else { setAll(0, 0, 0, 0); strip.show(); }
    }

    // External control overrides motion detection while active
    if (g_pendingExtCmd > 0) {
      applyExtCommand(g_pendingExtCmd);
      g_pendingExtCmd = 0;
    }
    if (g_extActive) {
      extWasActive = true;
      serviceExtControl();
      yield();
      delay(50);
      continue;   // skip PIR / night / day handling this iteration
    }
    // Override just ended (clear / timeout / green_fade done): ignore any lingering
    // PIR HIGH (e.g. the person who was vacuuming) until the sensors next read idle,
    // so we don't fire an animation on stale presence.
    if (extWasActive) {
      extWasActive = false;
      ignoreMotionUntilLow = true;
    }

    bool night = isNightMode(currenttime);

    // 23–6 h: night mode; strip stays off when idle, PIR triggers nightAnimation below
    if (night) {
      if (!wasNightMode) {
        setAll(0, 0, 0, 0);
        strip.show();
        wasNightMode = true;
      }
    } else {
      if (wasNightMode) {
        setAll(0, 0, 0, 0);
        strip.show();
        wasNightMode = false;
      }
    }

    int pir1 = digitalRead(PIR1);
    int pir2 = digitalRead(PIR2);

#if DEBUG
    // Every ~2 s: print PIR state (heartbeat)
    if (count % 20 == 0) {
      Serial.printf("[%lu] PIR1=%s PIR2=%s  (PIR1=UP, PIR2=DOWN)\n",
                    millis() / 1000, pir1 == HIGH ? "HIGH" : "low ", pir2 == HIGH ? "HIGH" : "low ");
    }
    // Report immediately on state change
    if (pir1 != lastPir1 || pir2 != lastPir2) {
      Serial.printf("      PIR changed -> PIR1=%s PIR2=%s\n", pir1 == HIGH ? "HIGH" : "low ", pir2 == HIGH ? "HIGH" : "low ");
      lastPir1 = pir1;
      lastPir2 = pir2;
    }
#endif

    if (pir1 == HIGH) { dir = "UP"; }
    if (pir2 == HIGH) { dir = "DOWN"; }

    // After an external override ended, wait for both PIRs to read idle once before
    // re-arming, so leftover presence from the override can't trigger an animation.
    if (ignoreMotionUntilLow) {
      if (pir1 == LOW && pir2 == LOW) ignoreMotionUntilLow = false;  // re-armed
      dir = "";                                                       // ignore until then
    }

    if (night && dir != "") {
#if DEBUG
      Serial.println(">>> PIR triggered (night): " + dir + " -> night animation");
#endif
      addMotionLog(dir.c_str(), 6);
      runAnimation(6, dir);
      for (unsigned long t = millis(); millis() - t < (unsigned long)POST_ANIM_DELAY_MS && g_pendingExtCmd == 0; ) {
        ArduinoOTA.handle();
        delay(100);
      }
    } else if (!night && automationOn && dir != "") {
#if DEBUG
      Serial.println(">>> PIR triggered: " + dir + " -> starting animation");
#endif
      if (isBirthdayToday(currenttime)) {
        addMotionLog(dir.c_str(), 5);  // 5 = Birthday
        runAnimation(5, dir);
        // 10 s delay after birthday animation (same as others)
        for (unsigned long t = millis(); millis() - t < (unsigned long)POST_ANIM_DELAY_MS && g_pendingExtCmd == 0; ) {
          ArduinoOTA.handle();
          delay(100);
        }
      } else {
        // Random pick, but not the same animation as last time (birthday and night red
        // have their own days/hours)
        static const uint8_t CHOICES[] = { 2, 3, 4, 7 };
        int choice;
        do {
          choice = CHOICES[random(sizeof(CHOICES))];
        } while (choice == lastAnimation);
        lastAnimation = choice;
        addMotionLog(dir.c_str(), (uint8_t)choice);

        runAnimation((uint8_t)choice, dir);
        // 10 s delay after animation (OTA and web stay available)
        for (unsigned long t = millis(); millis() - t < (unsigned long)POST_ANIM_DELAY_MS && g_pendingExtCmd == 0; ) {
          ArduinoOTA.handle();
          delay(100);
        }
      }
    }
    dir = "";

    if (count++ > 100) {
      currenttime = ntpClient.getUnixTime();
      g_lastNtpTime = currenttime;
      if (s_bootTimeUtc == 0 && currenttime > 0) s_bootTimeUtc = currenttime;
#if DEBUG
      Serial.printf("NTP time: %d\n", currenttime);
#endif
      count = 0;
    }
    yield();
    delay(100);
  }
}

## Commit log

2018-03-30 first almost working version, it now chooses a random colour, fading out strangely does not work yet
    [parking.h, rgbw_stair_light.ino]
2018-04-02 removed a bug in the stepfade function
    [parking.h, rgbw_stair_light.ino]
2018-09-07 a few changes
    [stair-light-project.kicad_pcb, stair-light-project.sch]
2018-11-17 Added schematics
2026-03-15 added reboot, status table, movement log and reboot to webUI
    [minimal_ota.ino.cpp, rgbw_stair_light.ino]
2026-04-03 Add night mode indicator, firmware version to webUI, update docs
    - Night mode badge in web UI shows when night mode is active (1:00–6:00)
    - Firmware version (FW_VERSION) displayed at bottom of web UI
    - /api/state now includes "night" field
    - Added CHANGELOG.md
    - Updated README with current night mode defaults and new UI features
2026-04-04 Add design spec for AsyncWebServer migration and UI redesign
    Two-phase approach: Phase 1 swaps ESP8266WebServer for ESPAsyncWebServer
    (same UI), Phase 2 redesigns the web UI with sliders, animation buttons,
    collapsible diagnostics, and tiered polling.
2026-04-04 Phase 1a: Replace ESP8266WebServer with ESPAsyncWebServer, remove handleNetwork()
    [parking.h, rgbw_stair_light.ino]
2026-04-04 Phase 2: Rewrite web UI with sliders, animation buttons, collapsible diagnostics, tiered polling
2026-04-04 Bump firmware version to 2.0.0 for AsyncWebServer + UI redesign
    [rgbw_stair_light.ino]
2026-06-06 Scope color-preset click handler to [data-all] to avoid Save button collision
    [rgbw_stair_light.ino]
2026-06-06 Add GET/POST /api/birthdays (replace-all, validated, persisted)
    [rgbw_stair_light.ino]
2026-06-06 Reject non-numeric count in /api/birthdays (avoid silent list clear)
    [rgbw_stair_light.ino]
2026-06-07 Fix night mode across midnight; label birthday Month/Day fields (2.2.1)
    - isNightMode handles start>end windows (e.g. 23-6) via wrap-around
    - Birthdays editor: Month/Day/Name column headers + MM/DD placeholders
    [rgbw_stair_light.ino]
2026-06-07 Add 5-minute safety timeout for held external-control states (2.4.0)
    Held states (red, red_blink, yellow_blink) auto-release after 5 min with no
    new /api/ext command, returning to normal operation. Each command resets the
    timer; green_fade is unaffected (self-terminates ~30s). Prevents the stairs
    getting stuck if the controller crashes or loses WiFi. Includes spec + plan docs.
    [rgbw_stair_light.ino]
2026-06-07 Add 'clean' (Staubsaugen) cleaning-light state with 10-min auto-off (2.5.0)
    POST /api/ext state=clean -> all LEDs full brightness (255 all channels), held
    up to 10 min or until state=clear. Per-mode hold timeout (clean=10min, others=5min).
    For Siri via an Apple Shortcut. Includes spec + plan docs and README Siri setup.
    [rgbw_stair_light.ino]
2026-06-07 Fix spurious animation after external override ends (2.5.2)
    After an override clears (clear / timeout / green_fade), ignore the PIR until it
    next reads idle, so lingering presence from e.g. cleaning ('Staubsaugen aus')
    doesn't immediately trigger an animation. Fresh motion still triggers.
    [rgbw_stair_light.ino]
2026-06-08 Privacy: gitignore CLAUDE.md/.claude; remove device IP from README (use placeholder)
2026-06-08 External control preempts running animations (2.7.0)
    Animation hold-phases and the post-animation delay now abort when an /api/ext
    command is pending, so the strip switches to the requested state in ~1-2s
    instead of up to ~30s. Covers all animations + night animation.
2026-10-05 Animation overhaul, Matrix rain and new web UI (2.8.0)
    Rainbow, star sparkle and birthday fade in and out as smooth waves and
    run their full duration; new Matrix digital-rain animation; random colour
    removed. Redesigned web UI served from web_ui.h. The automation switch is
    now saved on the device, so every device can run the same build.
    [parking.h, rgbw_stair_light.ino]
2026-10-05 Upload scripts: compile only when changed, upload to several devices
    One build can go to the testbed and production in a single run with one
    password prompt; the firewall is re-enabled even on failure or Ctrl+C.
    Termius added to the firewall allow list.
2026-10-07 Ignore macOS and KiCad local files; stop tracking .DS_Store
    KiCad's local history (which contains its own .git), footprint cache and
    automatic backups, .DS_Store files and the brainstorming tool's working
    folder stay out of the repository.
2026-10-07 KiCad: add PCB project with Gerbers; update project settings
    Adds the stair-ligh-project board (schematic, PCB, project files and the
    Gerber/drill set used for manufacturing). The main project files pick up
    settings written by the newer KiCad version.
    [stair-ligh-project-B_Cu.gbr, stair-ligh-project-B_Mask.gbr, stair-ligh-project-B_Paste.gbr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]
2026-10-07 README: describe the new web UI
    Rewrites the web UI section for the 2.8 page (animation tiles, fixed
    colour, recent motion, device panel, settings, birthdays, API) and updates
    the intro, startup signal, night mode notice, animation list, project and
    script tables. Notes that OTA uploads only work between animations.
